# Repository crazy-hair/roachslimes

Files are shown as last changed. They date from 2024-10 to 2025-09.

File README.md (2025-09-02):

# roachslimes

This document is no longer being updated and will only be corrected on major updates! For full documentation please check out [The Docs](https://crazy-hair.github.io/roachslimes/)

A utilitarian tracker design for [SlimeVR](https://docs.slimevr.dev/), with the intention of using the cheapest parts available in the smallest form factor possible, while maintaining quality and usability.

## Ordering PCBs

**NEW!** Revision 2 motherboards have been added, removing the BMI160-QMC5883 IMU-Magnetometer combo, and replacing it with an [LSM6DSR](https://moffshop.deyta.de/products/lsm6dsr) board which has a magnetometer built in. Technically, the LSM6DSR board is pin-compatible with the BMI160 (and therefore is compatible with the old rev 1 boards), but this new design allows for much easier direct mounting (instead of using pin headers) and frees up space for a battery connector, instead of directly soldering the battery to the board. They're currently untested, still waiting for my batch to arrive, so use at your own risk!

The included gerbers in `/PCB/Production/` are exported from KiCad using the recommended settings for [JLCPCB](https://jlcpcb.com). I cannot guarantee that they will work at a different fab. JLCPCB is far and away the most cost effective for low volume PCB orders, coming out to $3.52 for 20 boards before tax if you use their economy shipping option (as of 2024). There are four files, two for each board (one single board, and one panelized). Using the panelized board files is highly recommended, as it allows for More Board Per Board<sup>TM</sup> without additional cost. The default JLCPCB order parameters are good enough for working boards out of the box, but I'd recommend changing the color to yellow [(because it's lemon scented)](https://x.com/MKVRiscy/status/1821870120697987492) and to select "no mark" so you don't have some unique identifier printed on the board somewhere.

## Ordering Parts

Links to all required components can be found in the table futher down.

## Printing Instructions

The print files, STLs, and Fusion source files are included in the `/3D Files/` directory. I highly recommend using the `.3mf` print files as a basis for your print, as there are manually painted supports and custom settings per object (there's one `.3mf` for PrusaSlicer and friends and one for OrcaSlicer and friends).

## Assembly

This board is designed to be compact, which means I had to make some unconventional choices during assembly. The D1 Mini and TP-4056 Boards are mounted to the surface of the PCB, while the BMI and QMC are mounted on headers on the opposite side. For assembly, this means you have to solder the headers on first, then use flush cutters or snips to cut the header pins sticking out of the front of the board down to be flush so you can solder on the boards on the onto the front. There's also a pogo pin header for a future modular charging dock which would allow for charging multiple trackers at once, and a slot for an LED and associated resistor which was added for debugging but can be used to identify trackers if you choose to use different colored LEDs per tracker. The cases are completely toolless and are friction/retention fit. Refer to the animation below for an assembly reference.

## Firmware

Firmware is pretty straightforward, though I did have an issue with the Butterscotch builder/installer - battery sense would always show 100 percent. Therefore, if you want all features to work, I'd recommend building it yourself - PlatformIO Tools for Visual Studio Code make it super easy. If you're compiling yourself, all you have to do is uncomment out `BATTERY_SHIELD_RESISTANCE 180` in `defines.h`, set `USE_6_AXIS false` in `debug.h`, and and change `BMI160_MAG_TYPE BMI160_MAG_TYPE_HMC` to `BMI160_MAG_TYPE BMI160_MAG_TYPE_QMC`in `defines_bmi160.h`. If that makes no sense to you, I've included compiled firmware in the releases section. 

## Price Breakdown

A fully parametric breakdown that allows for adjusting tax, quantity, and more can be found in BOM.xlsx or [here](https://docs.google.com/spreadsheets/d/1RTwIJsGUY1e1f047yFT5OwqJSmgT3SN4hO7gHYImR_g/copy) (if you want to modify it, you'll have to make a copy first).

All prices are in USD. Sales tax is calculated at 8.25%. The table is based on a full set of trackers and includes 2 extra D1s, BMIs, and QMCs to account for possible DOA parts or accidents during assembly. Note that the LED and associated 620Ω resistor, as well as the pogo pins are not necessary for core tracker operation, as specified in the comment row.

| Tracker Components | [D1 Mini v4](https://www.aliexpress.us/item/32831353752.html) | [BMI160](https://www.aliexpress.us/item/1005007143698152.html) | [TP-4056](https://www.aliexpress.us/item/1005006379403615.html) | [GY-271](https://www.aliexpress.us/item/1556804905.html) | [SK12D07VG4](https://www.aliexpress.us/item/3256806149664764.html) | [JST-PH-4P](https://www.aliexpress.us/item/33011797617.html) | [Pogo Female](https://www.aliexpress.us/item/3256804960956555.html) | [B5817WS](https://www.aliexpress.us/item/1005004633629467.html) | [0805 180k](https://www.aliexpress.us/item/1005007032369041.html) | [0806 620r](https://www.aliexpress.us/item/3256806846054289.html) | [0805 LED](https://www.aliexpress.us/item/3256805245629305.html) | [803450](https://www.aliexpress.us/item/1005003621836701.html) | [Wires](https://www.aliexpress.us/item/1005007558078161.html) | Motherboard | Daughterboard | Total |
| --- | --- | --- | --- | --- | --- | --- | --- | --- | --- | --- | --- | --- | --- | --- | --- | --- |
| Listing Price | $1.43 | $0.88 | $3.27 | $0.58 | $1.20 | $3.79 | $12.93 | $1.20 | $1.05 | $1.05 | $2.47 | $25.99 | $11.93 | $2.00 | $2.00 | |
| Shipping | $2.63 | $2.32 | $ \- | $ \- | $ \- | $ \- | $ \- | $ \- | $ \- | $ \- | $ \- | $ \- | $ \- | $1.52 | $1.52 | $7.99 |
| Subtotal | $15.50 | $12.88 | $3.27 | $6.96 | $1.20 | $3.79 | $12.93 | $1.20 | $1.05 | $1.05 | $2.47 | $25.99 | $11.93 | $3.52 | $3.52 | $107.26 |
| Tax | $1.28 | $1.06 | $0.27 | $0.57 | $0.10 | $0.31 | $1.07 | $0.10 | $0.09 | $0.09 | $0.20 | $2.14 | $0.98 | $0.29 | $0.29 | $8.85 |
| Total | $16.78 | $13.94 | $3.54 | $7.53 | $1.30 | $4.10 | $14.00 | $1.30 | $1.14 | $1.14 | $2.67 | $28.13 | $12.91 | $3.81 | $3.81 | $116.11 |
| Order Quantity | 9 | 12 | 1 | 12 | 1 | 1 | 1 | 1 | 1 | 1 | 1 | 1 | 1 | 1 | 1 | |
| Item Quantity | 1 | 1 | 20 | 1 | 20 | 100 | 20 | 100 | 100 | 100 | 600 | 10 | 12 | 20 | 40 | |
| Price Per Unit | $1.86 | $1.16 | $0.18 | $0.63 | $0.06 | $0.04 | $0.70 | $0.01 | $0.01 | $0.01 | $0.00 | $2.81 | $1.08 | $0.19 | $0.10 | |
| | | | | | | | | | | | | | | | | |
| Quantity Per Primary Tracker | 1 | 1 | 1 | 1 | 1 | 1 | 1 | 2 | 1 | 1 | 1 | 1 | 0 | 1 | 0 | |
| Quantity Per Secondary Tracker | 0 | 1 | 0 | 1 | 0 | 1 | 0 | 0 | 0 | 0 | 0 | 0 | 1 | 0 | 1 | |
| | | | | | | | | | | | | | | | | |
| Price Per Primary Tracker | $1.86 | $1.16 | $0.18 | $0.63 | $0.06 | $0.04 | $0.70 | $0.03 | $0.01 | $0.01 | $0.00 | $2.81 | $ \- | $0.19 | $ \- | $7.69 |
| Price Per Secondary Tracker | $ \- | $1.16 | $ \- | $0.63 | $ \- | $0.04 | $ \- | $ \- | $ \- | $ \- | $ \- | $ \- | $1.08 | $ \- | $0.10 | $3.00 |
| | | | | | | | | | | | | | | | | |
| Comment | | | | | | | Optional | | | Optional | Optional | | | | | |

## Gallery

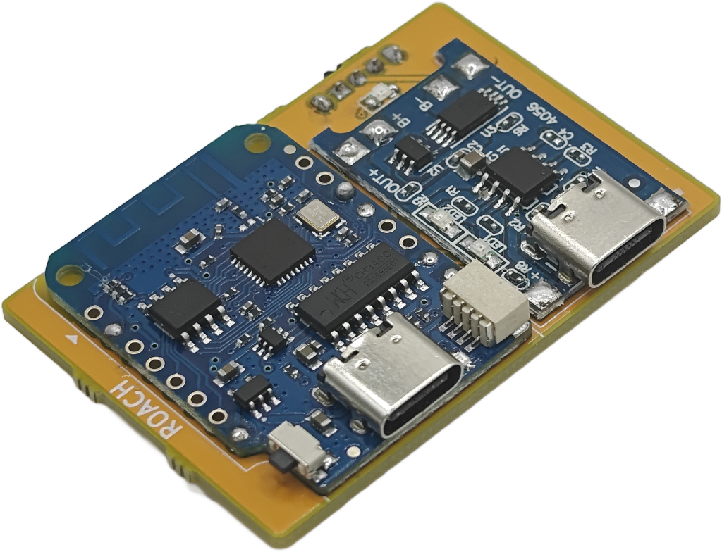
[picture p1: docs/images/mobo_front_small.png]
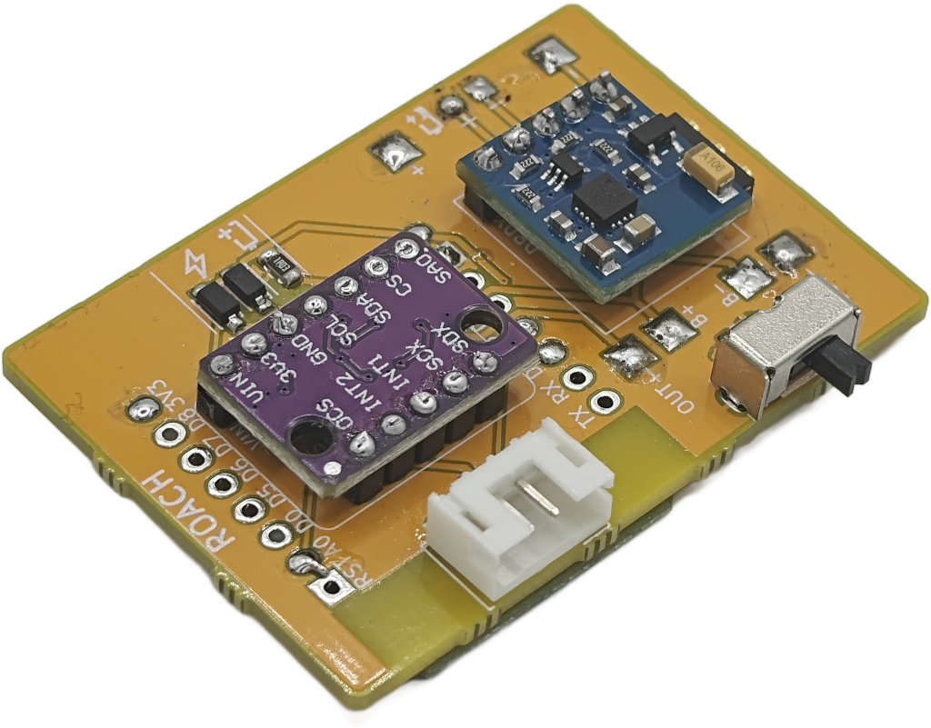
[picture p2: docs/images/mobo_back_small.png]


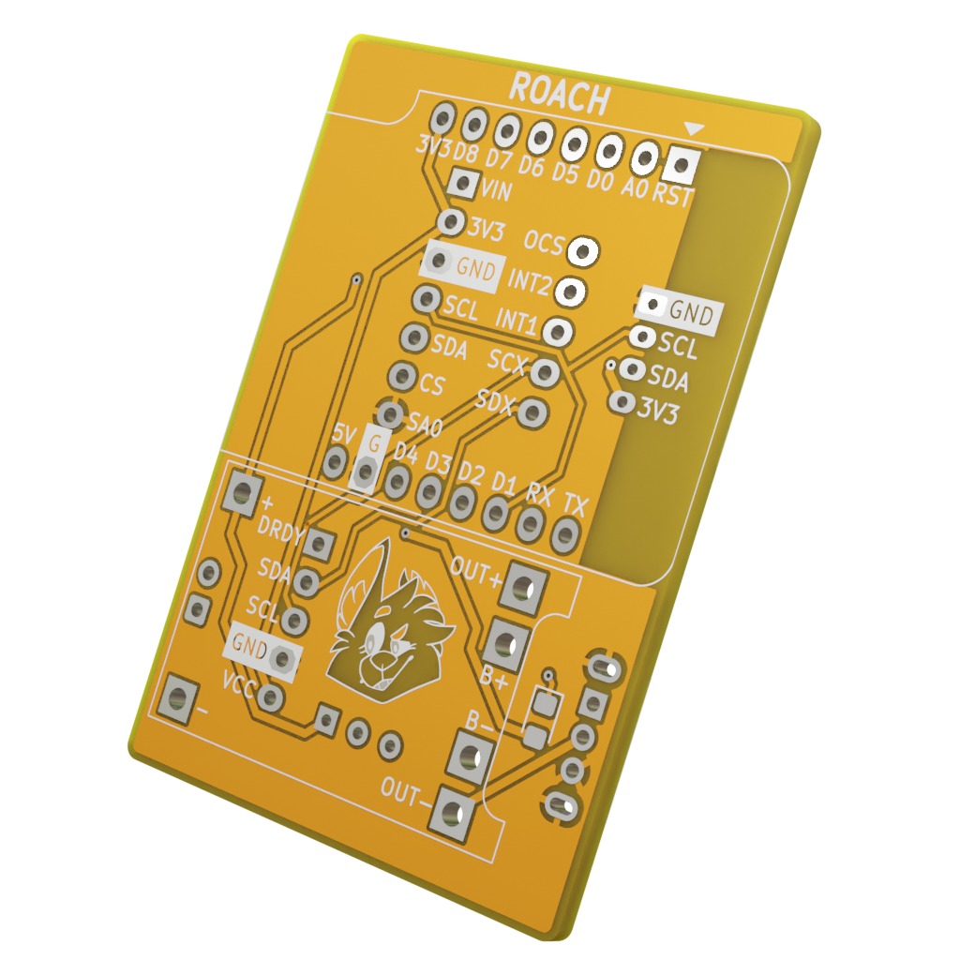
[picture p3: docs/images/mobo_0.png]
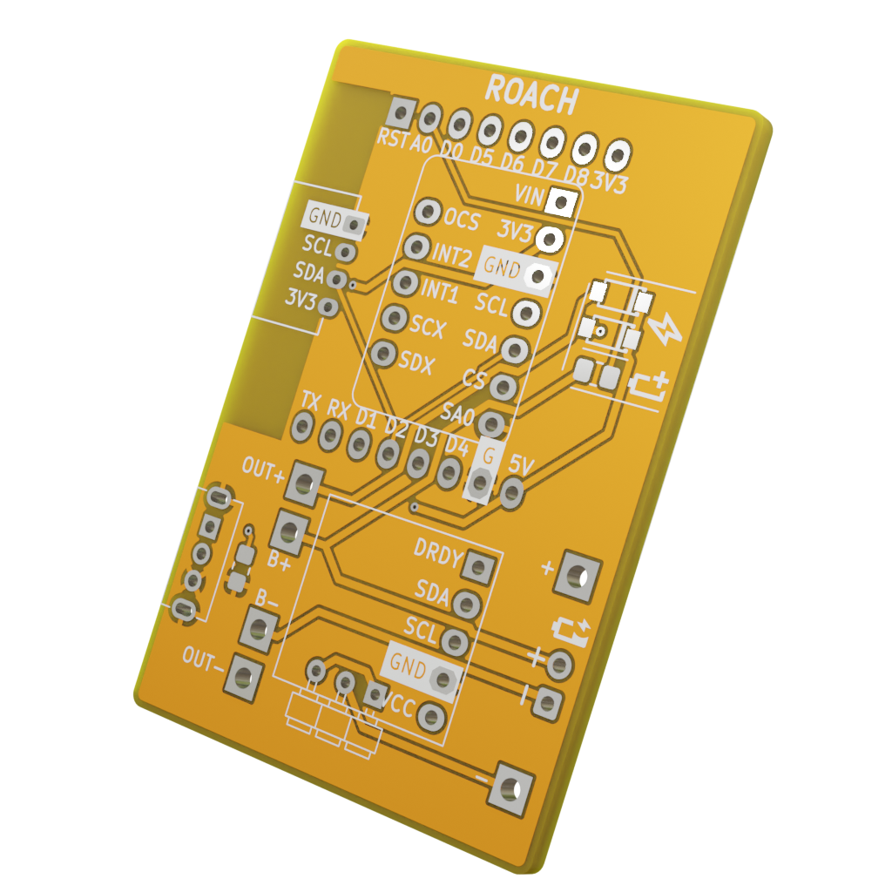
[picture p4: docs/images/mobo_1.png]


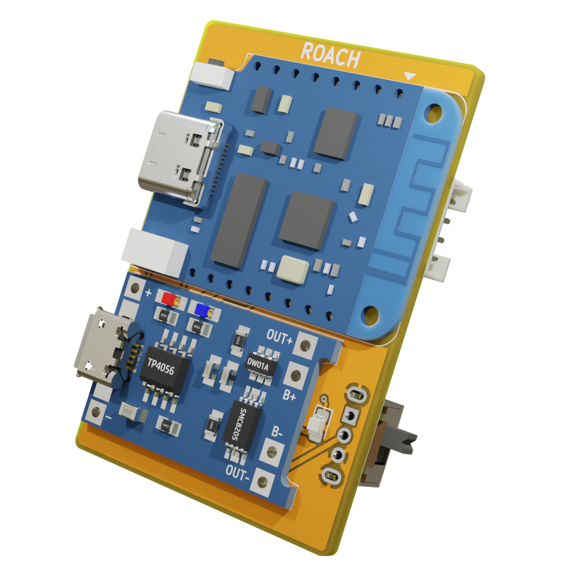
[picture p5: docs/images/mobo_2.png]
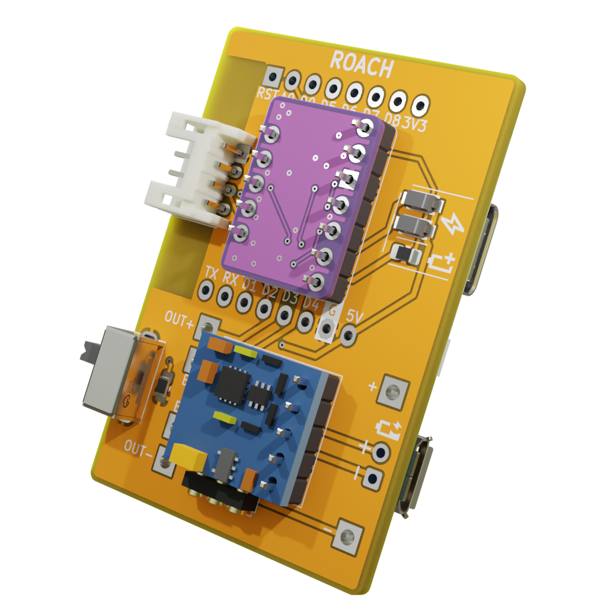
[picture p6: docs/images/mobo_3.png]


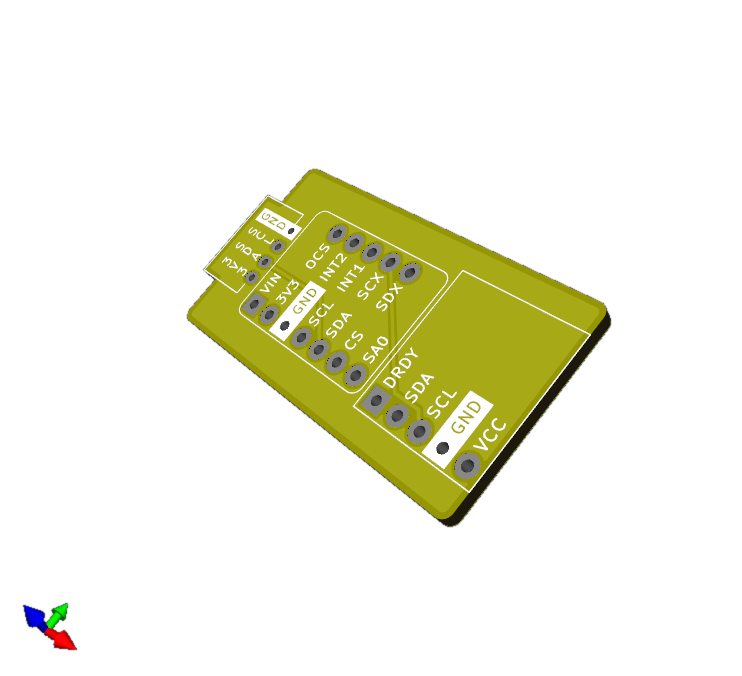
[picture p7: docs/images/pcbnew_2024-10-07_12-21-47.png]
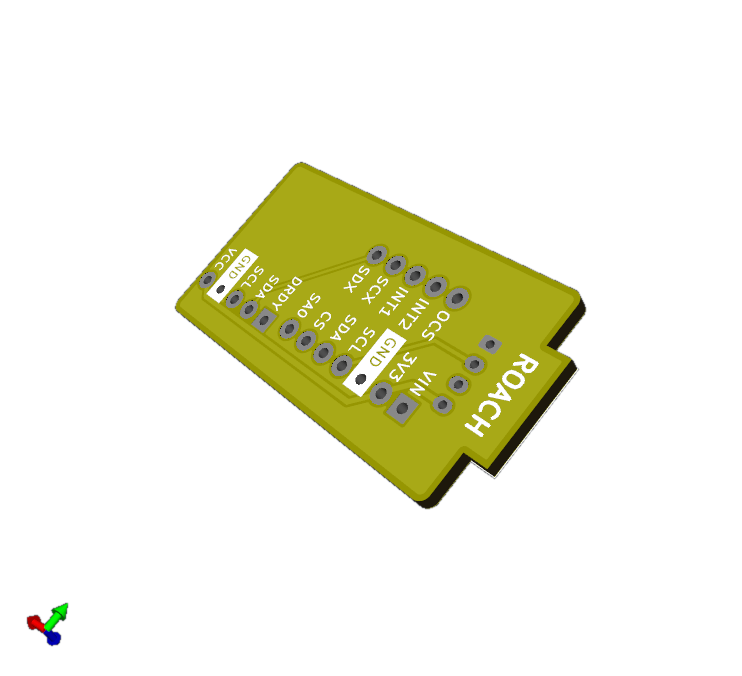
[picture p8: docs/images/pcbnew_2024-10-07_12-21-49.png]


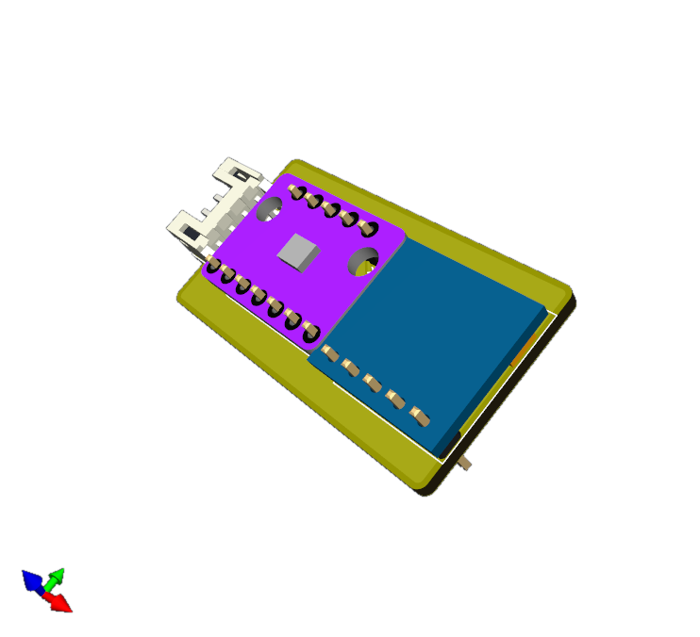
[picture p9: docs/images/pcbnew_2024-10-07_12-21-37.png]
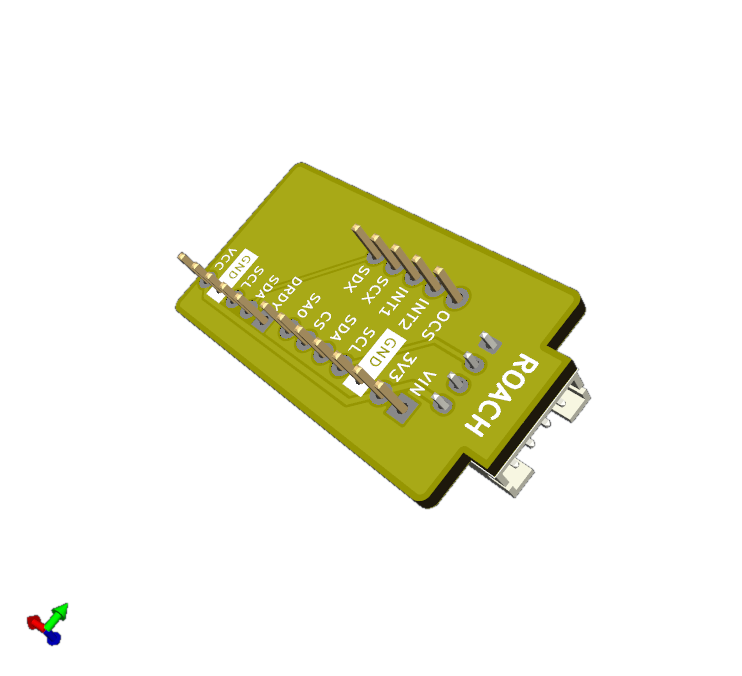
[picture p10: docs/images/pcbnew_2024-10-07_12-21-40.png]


## Credits

List of models used:

| Model | Credit |
|--|--:|
| Wemos D1 Mini v4 | [FBMinis](https://grabcad.com/library/wemos-esp8266-lolin-d1-mini-v4-1) |
| TP-4056 | [Babu George](https://grabcad.com/library/03962a-hw107-lithium-battery-charging-module-1) |
| BMI160 | [Kouno](https://store.kouno.xyz/products/bmi270-breakout-board) |
| GY-271 | [Benas Griauzde](https://grabcad.com/library/gy-271-hmc5883l-triple-3-axis-digital-compass-magnetometer-sensor-module-1) |

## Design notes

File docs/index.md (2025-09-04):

---
title: Main Page
nav_order: 0
---

This documentation is a work in progress! If you have any questions, feel free to send me a message request on discord at `crazy.hair`.

# roachslimes

A utilitarian DIY tracker design for [SlimeVR](https://docs.slimevr.dev/), with the intention of using the cheapest parts available in the smallest form factor possible, while maintaining quality, usability, and the ability to be built by hand.

Check out the sidebar for more information on building them yourself!

**NEW!** Revision 2 motherboards have been added, removing the BMI160-QMC5883 IMU-Magnetometer combo, and replacing it with an [LSM6DSR](https://moffshop.deyta.de/products/lsm6dsr) board which has a magnetometer built in. Technically, the LSM6DSR board is pin-compatible with the BMI160 (and therefore is compatible with the old rev 1 boards), but this new design allows for much easier direct mounting (instead of using pin headers) and frees up space for a battery connector, instead of directly soldering the battery to the board. They're currently untested, still waiting for my batch to arrive, so use at your own risk!

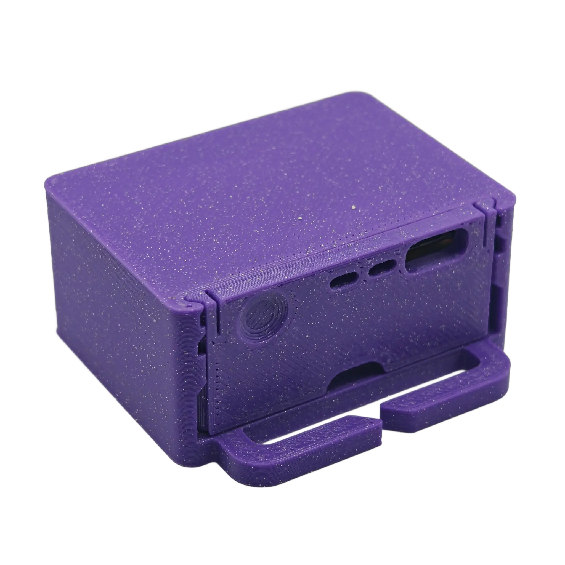
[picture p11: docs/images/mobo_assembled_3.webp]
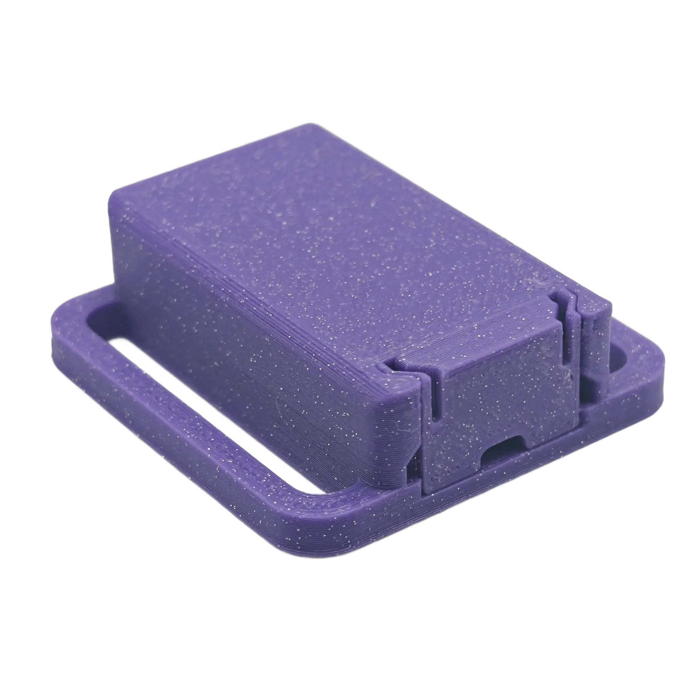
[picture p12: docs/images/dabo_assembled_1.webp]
  <br>

Feel free to take the boards for a spin, they're 3D models!

<iframe src="rendering/mobo_viewer.html" name="mobo_viewer" scrolling="no" frameborder="1" marginheight="0px" marginwidth="0px" style="width:49%; aspect-ratio:1/1; border-width: 0" allowfullscreen></iframe>
<iframe src="rendering/dabo_viewer.html" name="dabo_viewer" scrolling="no" frameborder="1" marginheight="0px" marginwidth="0px" style="width:49%; aspect-ratio:1/1; border-width: 0" allowfullscreen></iframe>

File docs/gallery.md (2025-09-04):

---
title: Gallery
nav_order: 5
---

# Gallery
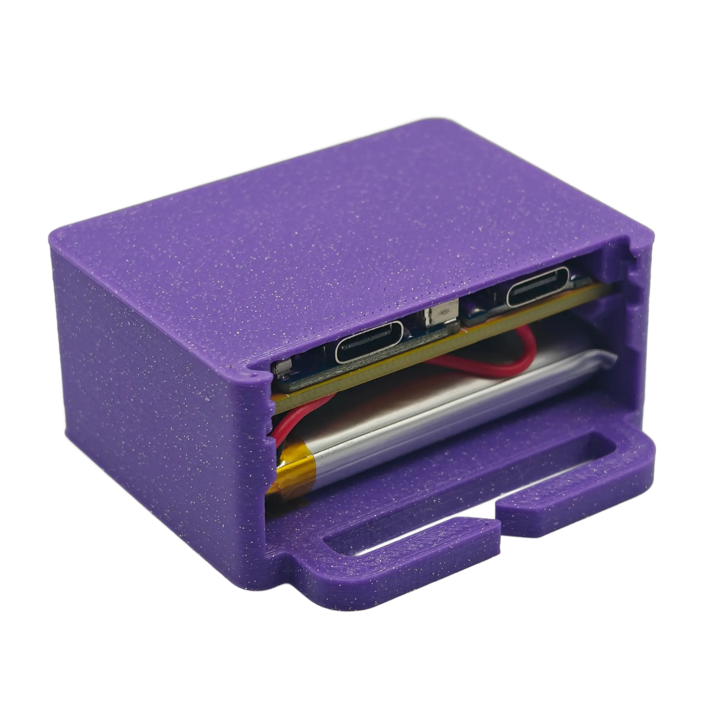
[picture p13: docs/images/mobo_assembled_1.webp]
  <br>
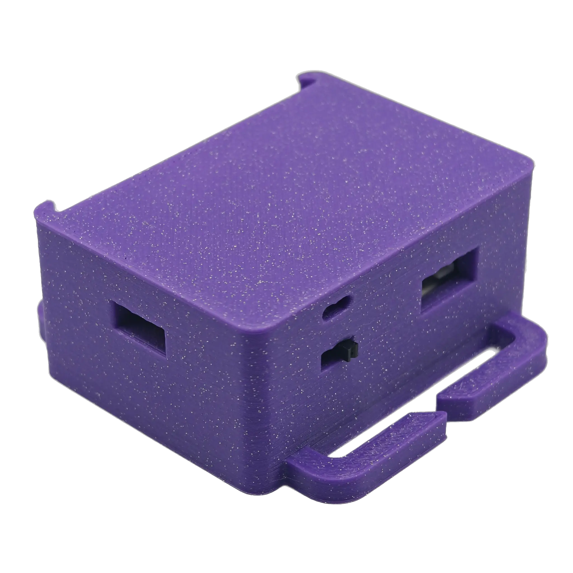
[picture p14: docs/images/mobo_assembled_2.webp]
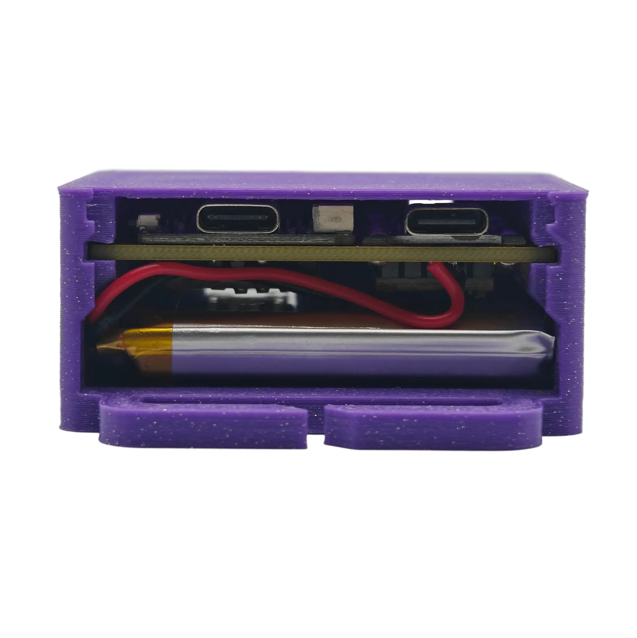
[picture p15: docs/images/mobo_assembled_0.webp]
  <br>
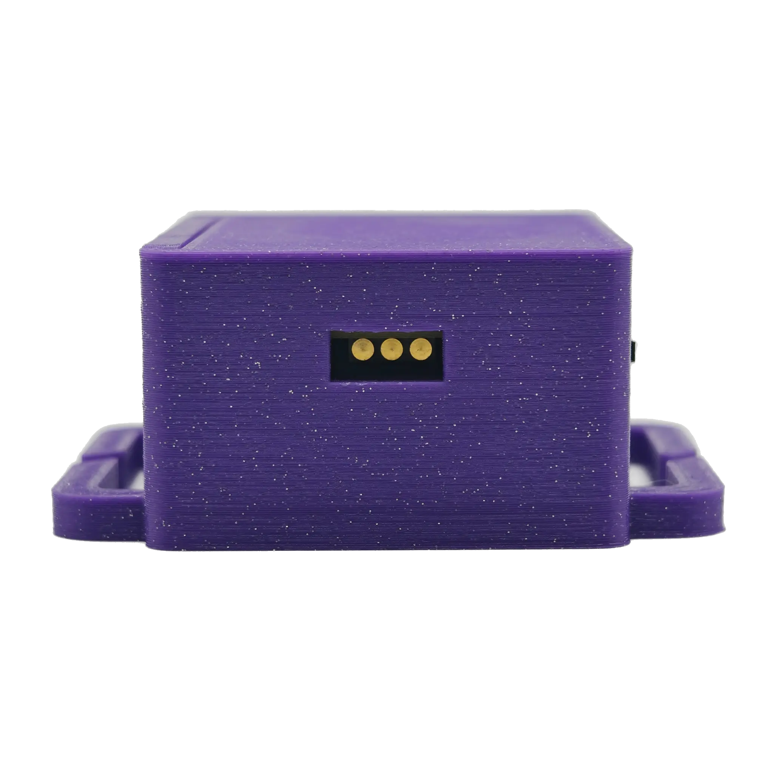
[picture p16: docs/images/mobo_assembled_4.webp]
  <br>
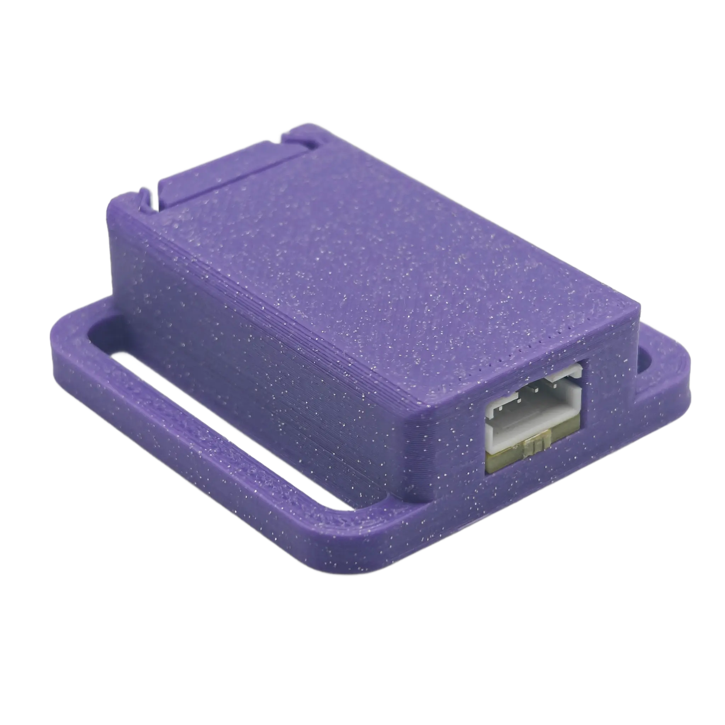
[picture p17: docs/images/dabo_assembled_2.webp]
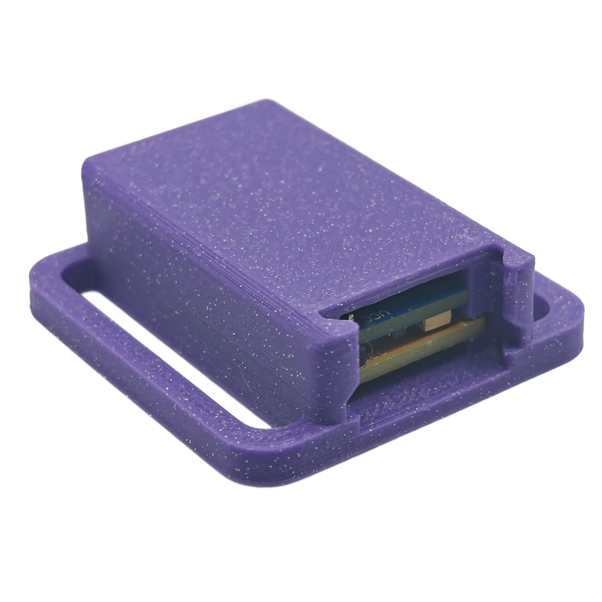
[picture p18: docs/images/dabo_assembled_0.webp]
  <br>
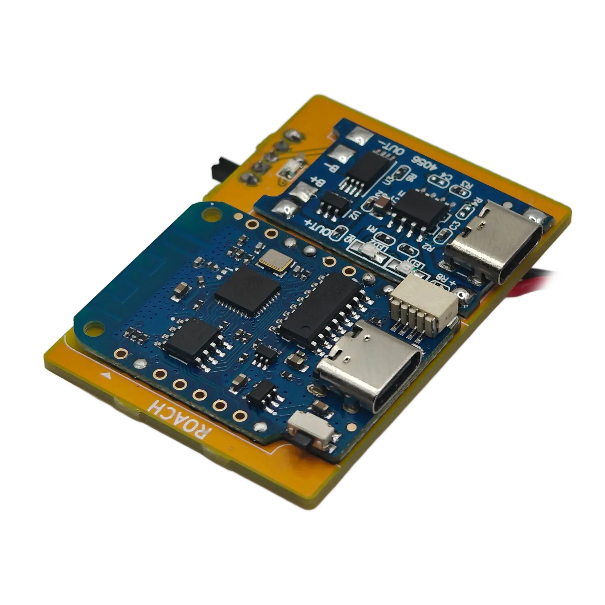
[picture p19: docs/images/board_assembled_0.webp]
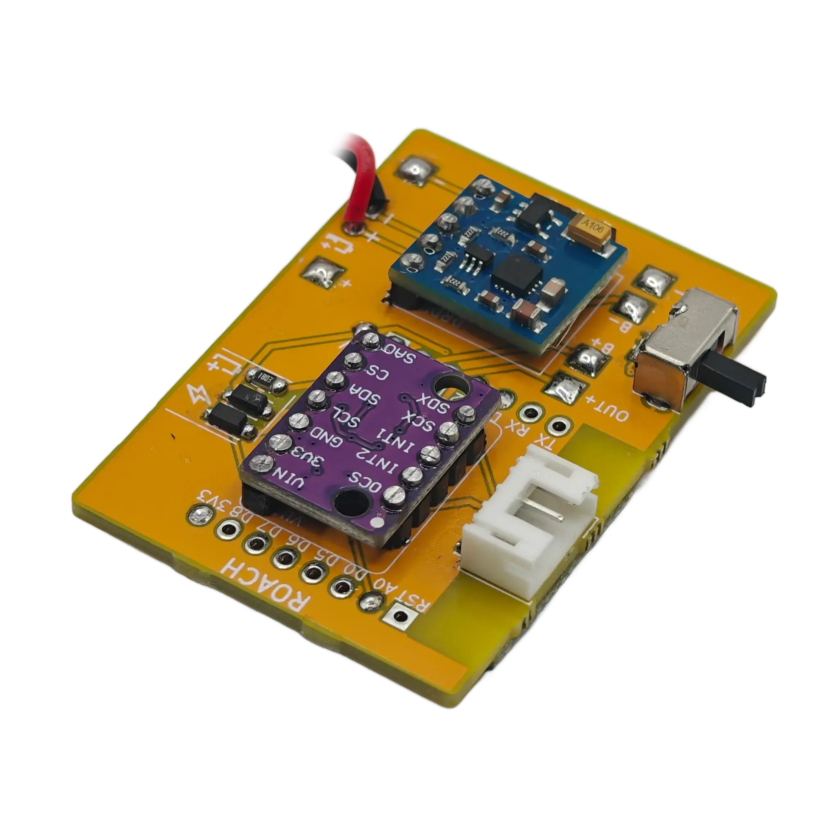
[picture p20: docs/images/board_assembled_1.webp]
  <br>
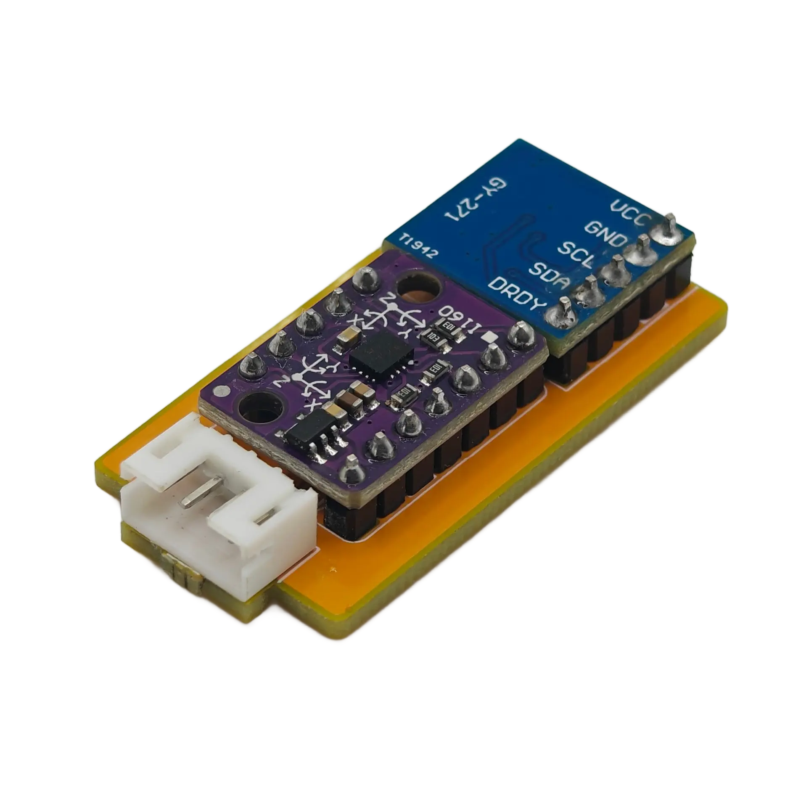
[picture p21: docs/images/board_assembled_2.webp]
 <br>
  <br>
  <br>
  <br>
  <br>

<video src="videos/floatybouncy_mobo.mp4" style="width:49%" autoplay loop muted></video> <video src="videos/floatybouncy_dabo.mp4" style="width:49%" autoplay loop muted></video> <br>
<video style="width:49%" src="videos/floatybouncy_mobo_case.mp4" autoplay loop muted></video> <video src="videos/floatybouncy_dabo_case.mp4" style="width:49%" autoplay loop muted></video> <br>

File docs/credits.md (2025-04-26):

---
title: Credits
nav_order: 6
---

# Credits

All PCB design, CAD, animation, rendering, and pretty much everything else was done by me.

As for all the stuff that I didn't make:

The SlimeVR spec and software were all designed by the [SlimeVR dev team](https://slimevr.dev/). Without them, this project wouldn't exist at all!

List of models used:

| Model | Credit |
|--|--:|
| Wemos D1 Mini v4 | [FBMinis](https://grabcad.com/library/wemos-esp8266-lolin-d1-mini-v4-1) |
| TP-4056 | [Babu George](https://grabcad.com/library/03962a-hw107-lithium-battery-charging-module-1) |
| BMI160 | [Kouno](https://store.kouno.xyz/products/bmi270-breakout-board) |
| GY-271 | [Benas Griauzde](https://grabcad.com/library/gy-271-hmc5883l-triple-3-axis-digital-compass-magnetometer-sensor-module-1) |

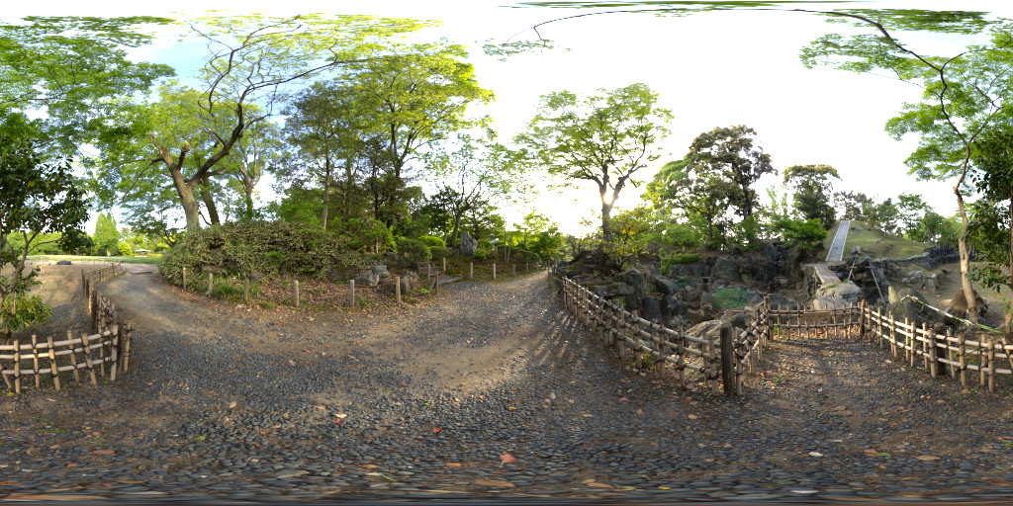
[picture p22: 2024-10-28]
docs/rendering/ninomaru_teien_1k.jpg

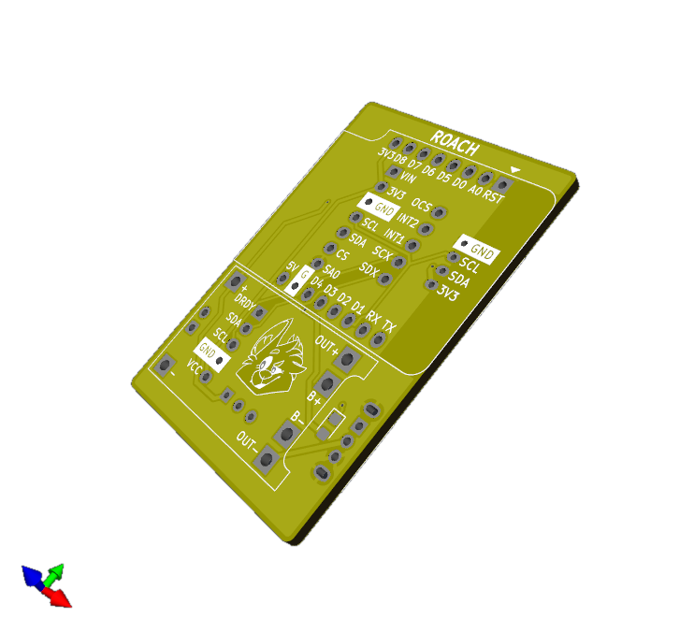
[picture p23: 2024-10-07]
docs/images/pcbnew_2024-10-07_12-25-15.png

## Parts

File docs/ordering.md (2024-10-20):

---
title: Sourcing and Ordering Parts
nav_order: 1
---

# Ordering PCBs

The included gerbers in [`/PCB/Production/`](https://github.com/crazy-hair/roachslimes/tree/main/PCB/Production) are exported from KiCad using the recommended settings for [JLCPCB](https://jlcpcb.com). I cannot guarantee that they will work at a different fab. JLCPCB is far and away the most cost effective for low volume PCB orders, coming out to $3.52 for 20 boards before tax if you use their economy shipping option (as of 2024). There are four files, two for each board (one single board, and one panelized). Using the panelized board files is highly recommended, as it allows for More Board Per Board<sup>TM</sup> without additional cost. The default JLCPCB order parameters are good enough for working boards out of the box, but I'd recommend changing the color to yellow [(because it's lemon scented)](https://x.com/MKVRiscy/status/1821870120697987492) and to select "no mark" so you don't have some unique identifier printed on the board somewhere.

# Ordering Parts

Links to all required components can be found in the headers of the table. 

A fully parametric breakdown that allows for adjusting tax, quantity, and more can be found in the Excel file [BOM.xlsx](https://github.com/crazy-hair/roachslimes/blob/main/BOM.xlsx) or [the Google Sheets page](https://docs.google.com/spreadsheets/d/1RTwIJsGUY1e1f047yFT5OwqJSmgT3SN4hO7gHYImR_g/copy) (if you want to modify it, you'll have to make a copy first).

All prices are in USD. Sales tax is calculated at 8.25%. The table is based on a full set of trackers and includes 2 extra D1s, BMIs, and QMCs to account for possible DOA parts or accidents during assembly. Note that the LED and associated 620Ω resistor, as well as the pogo pins are not necessary for core tracker operation, as specified in the comment row.

The table scrolls horizontally, it was too wide to fit.

| Tracker Components | [D1 Mini v4](https://www.aliexpress.us/item/32831353752.html) | [BMI160](https://www.aliexpress.us/item/1005007143698152.html) | [TP-4056](https://www.aliexpress.us/item/1005006379403615.html) | [GY-271](https://www.aliexpress.us/item/1556804905.html) | [SK12D07VG4](https://www.aliexpress.us/item/3256806149664764.html) | [JST-PH-4P](https://www.aliexpress.us/item/33011797617.html) | [Pogo Female](https://www.aliexpress.us/item/3256804960956555.html) | [B5817WS](https://www.aliexpress.us/item/1005004633629467.html) | [0805 180k](https://www.aliexpress.us/item/1005007032369041.html) | [0806 620r](https://www.aliexpress.us/item/3256806846054289.html) | [0805 LED](https://www.aliexpress.us/item/3256805245629305.html) | [803450](https://www.aliexpress.us/item/1005003621836701.html) | [Wires](https://www.aliexpress.us/item/1005007558078161.html) | Motherboard | Daughterboard | Total |
| --- | --- | --- | --- | --- | --- | --- | --- | --- | --- | --- | --- | --- | --- | --- | --- | --- |
| Listing Price | $1.43 | $0.88 | $3.27 | $0.58 | $1.20 | $3.79 | $12.93 | $1.20 | $1.05 | $1.05 | $2.47 | $25.99 | $11.93 | $2.00 | $2.00 | |
| Shipping | $2.63 | $2.32 | $ \- | $ \- | $ \- | $ \- | $ \- | $ \- | $ \- | $ \- | $ \- | $ \- | $ \- | $1.52 | $1.52 | $7.99 |
| Subtotal | $15.50 | $12.88 | $3.27 | $6.96 | $1.20 | $3.79 | $12.93 | $1.20 | $1.05 | $1.05 | $2.47 | $25.99 | $11.93 | $3.52 | $3.52 | $107.26 |
| Tax | $1.28 | $1.06 | $0.27 | $0.57 | $0.10 | $0.31 | $1.07 | $0.10 | $0.09 | $0.09 | $0.20 | $2.14 | $0.98 | $0.29 | $0.29 | $8.85 |
| Total | $16.78 | $13.94 | $3.54 | $7.53 | $1.30 | $4.10 | $14.00 | $1.30 | $1.14 | $1.14 | $2.67 | $28.13 | $12.91 | $3.81 | $3.81 | $116.11 |
| Order Quantity | 9 | 12 | 1 | 12 | 1 | 1 | 1 | 1 | 1 | 1 | 1 | 1 | 1 | 1 | 1 | |
| Item Quantity | 1 | 1 | 20 | 1 | 20 | 100 | 20 | 100 | 100 | 100 | 600 | 10 | 12 | 20 | 40 | |
| Price Per Unit | $1.86 | $1.16 | $0.18 | $0.63 | $0.06 | $0.04 | $0.70 | $0.01 | $0.01 | $0.01 | $0.00 | $2.81 | $1.08 | $0.19 | $0.10 | |
| | | | | | | | | | | | | | | | | |
| Quantity Per Primary Tracker | 1 | 1 | 1 | 1 | 1 | 1 | 1 | 2 | 1 | 1 | 1 | 1 | 0 | 1 | 0 | |
| Quantity Per Secondary Tracker | 0 | 1 | 0 | 1 | 0 | 1 | 0 | 0 | 0 | 0 | 0 | 0 | 1 | 0 | 1 | |
| | | | | | | | | | | | | | | | | |
| Price Per Primary Tracker | $1.86 | $1.16 | $0.18 | $0.63 | $0.06 | $0.04 | $0.70 | $0.03 | $0.01 | $0.01 | $0.00 | $2.81 | $ \- | $0.19 | $ \- | $7.69 |
| Price Per Secondary Tracker | $ \- | $1.16 | $ \- | $0.63 | $ \- | $0.04 | $ \- | $ \- | $ \- | $ \- | $ \- | $ \- | $1.08 | $ \- | $0.10 | $3.00 |
| | | | | | | | | | | | | | | | | |
| Comment | | | | | | | Optional | | | Optional | Optional | | | | | |

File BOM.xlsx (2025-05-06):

Tracker Components | D1 Mini (https://www.aliexpress.us/item/32831353752.html) | BMI160 (https://www.aliexpress.us/item/1005007143698152.html) | TP4056 (https://www.aliexpress.us/item/1005006379403615.html) | GY-271 (https://www.aliexpress.us/item/1556804905.html) | SK12D07VG4 (https://www.aliexpress.us/item/3256806149664764.html) | JST-PH-4P (https://www.aliexpress.us/item/33011797617.html) | Pogo Female (https://www.aliexpress.us/item/3256804960956555.html) | B5817WS (https://www.aliexpress.us/item/1005004633629467.html) | 0805 180k (https://www.aliexpress.us/item/1005007032369041.html) | 0806 620r (https://www.aliexpress.us/item/3256806846054289.html) | 0805 LED (https://www.aliexpress.us/item/3256805245629305.html) | 803450 (https://www.aliexpress.us/item/1005003621836701.html) | Wires (https://www.aliexpress.us/item/1005007558078161.html) | Motherboard | Daughterboard | Total
Listing Price | $1.43 | $0.88 | $3.27 | $0.58 | $1.20 | $3.79 | $12.93 | $1.20 | $1.05 | $1.05 | $2.47 | $25.99 | $11.93 | $2.00 | $2.00
Shipping | $2.63 | $2.32 | $0.00 | $0.00 | $0.00 | $0.00 | $0.00 | $0.00 | $0.00 | $0.00 | $0.00 | $0.00 | $0.00 | $1.52 | $1.52 | $7.99
Subtotal | $15.50 | $12.88 | $3.27 | $6.96 | $1.20 | $3.79 | $12.93 | $1.20 | $1.05 | $1.05 | $2.47 | $25.99 | $11.93 | $3.52 | $3.52 | $107.26 |  | Tax Rate
Tax | $1.28 | $1.06 | $0.27 | $0.57 | $0.10 | $0.31 | $1.07 | $0.10 | $0.09 | $0.09 | $0.20 | $2.14 | $0.98 | $0.29 | $0.29 | $8.85 |  | 8.25%
Total | $16.78 | $13.94 | $3.54 | $7.53 | $1.30 | $4.10 | $14.00 | $1.30 | $1.14 | $1.14 | $2.67 | $28.13 | $12.91 | $3.81 | $3.81 | $116.11
Order Quantity | 9 | 12 | 1 | 12 | 1 | 1 | 1 | 1 | 1 | 1 | 1 | 1 | 1 | 1 | 1 |  |  | Materials Cost | Lower Body Set | Core Set | Enhanced Core Set | Full Body Set | Deluxe Tracker Set
Item Quantity | 1 | 1 | 20 | 1 | 20 | 100 | 20 | 100 | 100 | 100 | 600 | 10 | 12 | 20 | 40 |  |  | Primary Tracker Quantity | 5 | 5 | 5 | 7 | 10
Price Per Unit | $1.86 | $1.16 | $0.18 | $0.63 | $0.06 | $0.04 | $0.70 | $0.01 | $0.01 | $0.01 | $0.004456291667 | $2.81 | $1.08 | $0.19 | $0.10 |  |  | Secondary Tracker Quantity | 0 | 1 | 3 | 3 | 6 | Assembly Time Per Primary Tracker | 33
 |  |  |  |  |  |  |  |  |  |  |  |  |  |  |  |  |  |  |  |  |  |  |  | Assembly Time Per Secondary Tracker | 5
Quantity Per Primary Tracker | 1 | 1 | 1 | 1 | 1 | 1 | 1 | 2 | 1 | 1 | 1 | 1 | 0 | 1 | 0 |  |  | 500mm Strap Quantity | 6 | 8 | 8 | 10 | 10 | Assembly Time Per Charging Dock | 30
Quantity Per Secondary Tracker | 0 | 1 | 0 | 1 | 0 | 1 | 0 | 0 | 0 | 0 | 0 | 0 | 1 | 0 | 1 |  |  | 300mm Strap Quantity | 0 | 0 | 2 | 2 | 2
 |  |  |  |  |  |  |  |  |  |  |  |  |  |  |  |  |  |  |  |  |  |  |  | Hourly Wage | $22.00
Price Per Primary Tracker | $1.86 | $1.16 | $0.18 | $0.63 | $0.06 | $0.04 | $0.70 | $0.03 | $0.01 | $0.01 | $0.004456291667 | $2.81 | $0.00 | $0.19 | $0.00 | $7.69 |  | Price of Primary Trackers | $38.47 | $38.47 | $38.47 | $53.86 | $76.94
Price Per Secondary Tracker | $0.00 | $1.16 | $0.00 | $0.63 | $0.00 | $0.04 | $0.00 | $0.00 | $0.00 | $0.00 | $0.00 | $0.00 | $1.08 | $0.00 | $0.10 | $3.00 |  | Price of Secondary Trackers | $0.00 | $3.00 | $9.01 | $9.01 | $18.01
Comment |  |  |  |  |  |  | Optional |  |  | Optional | Optional |  |  |  |  |  |  | Price of 500mm Straps | $4.78 | $6.37 | $6.37 | $7.97 | $7.97
 |  |  |  |  |  |  |  |  |  |  |  |  |  |  |  |  |  | Price of 300mm Straps | $0.00 | $0.00 | $1.32 | $1.32 | $1.32
Ancillary Components | 38x300mm Strap (https://www.aliexpress.us/item/3256801722425879.html) | 38x500mm Strap (https://www.aliexpress.us/item/3256801722425879.html) | Chest Harness (https://www.aliexpress.us/item/2251832640172299.html)
Listing Price | $3.06 | $3.68 | $8.05 |  |  |  |  |  |  |  |  |  |  |  |  |  |  | Total Price of Set | $43.25 | $47.85 | $55.18 | $72.16 | $104.24
Shipping | $0.00 | $0.00 | $0.00
Subtotal | $6.12 | $7.36 | $8.05 |  |  |  |  |  |  |  |  |  |  |  |  |  |  | Assembly Cost | Lower Body Set | Core Set | Enhanced Core Set | Full Body Set | Deluxe Tracker Set
Tax | $0.50 | $0.61 | $0.66 |  |  |  |  |  |  |  |  |  |  |  |  |  |  | Total Price of Primary Assembly | $60.50 | $60.50 | $60.50 | $84.70 | $121.00
Total | $6.62 | $7.97 | $8.71 |  |  |  |  |  |  |  |  |  |  |  |  |  |  | Total Price of Secondary Assembly | $0.00 | $1.83 | $5.50 | $5.50 | $11.00
Order Quantity | 2 | 2 | 1 |  |  |  |  |  |  |  |  |  |  |  |  |  |  | Total Price of Assembly | $60.50 | $62.33 | $66.00 | $90.20 | $132.00
Item Quantity | 5 | 5 | 1
Price Per Unit | $0.66 | $0.80 | $8.71 |  |  |  |  |  |  |  |  |  |  |  |  |  |  | Total Price of Assembled Set | $103.75 | $110.18 | $121.18 | $162.36 | $236.24
Comment |  |  | Optional |  |  |  |  |  |  |  |  |  |  |  |  |  |  | Optional Addons | Lower Body Set | Core Set | Enhanced Core Set | Full Body Set | Deluxe Tracker Set
 |  |  |  |  |  |  |  |  |  |  |  |  |  |  |  |  | FALSE | Chest Harness | $0.00 | $0.00 | $0.00 | $0.00 | $0.00
Charging Dock Components | Pogo Male (https://www.aliexpress.us/item/2255800604645252.html) | USB-C Female SMD | PCB | Total |  |  |  |  |  |  |  |  |  |  |  |  | FALSE | Charging Dock | $0.00 | $0.00 | $0.00 | $0.00 | $0.00
Listing Price | $2.83 | $1.43 | $2.00 | $6.26 |  |  |  |  |  |  |  |  |  |  |  |  | FALSE | Identity LEDs | $0.00 | $0.00 | $0.00 | $0.00 | $0.00
Shipping | $0.00 | $0.00 | $1.52 | $1.52 |  |  |  |  |  |  |  |  |  |  |  |  | TRUE | 3D Printed Motherboard Cases | $8.45 | $8.45 | $8.45 | $11.83 | $16.90
Subtotal | $11.32 | $1.43 | $3.52 | $16.27 |  |  |  |  |  |  |  |  |  |  |  |  | TRUE | 3D Printed Daughterboard Cases | $0.00 | $0.83 | $2.49 | $2.49 | $4.98
Tax | $0.93 | $0.12 | $0.29 | $1.34
Total | $12.25 | $1.55 | $3.81 | $17.61 |  |  |  |  |  |  |  |  |  |  |  |  |  | Total Price of Addons | $8.45 | $9.28 | $10.94 | $14.32 | $21.88
Order Quantity | 4 | 1 | 1
Item Quantity | 5 | 10 | 5 |  |  |  |  |  |  |  |  |  |  |  |  |  |  | Total Price | $112.20 | $119.46 | $132.12 | $176.68 | $258.12
Price Per Unit | $0.61 | $0.15 | $0.76
Quantity Per Dock | 8 | 1 | 2
 |  |  |  |  |  | Assembled Price
Price Per Dock | $4.90 | $0.15 | $1.52 | $6.58 |  | $18.68
Comment

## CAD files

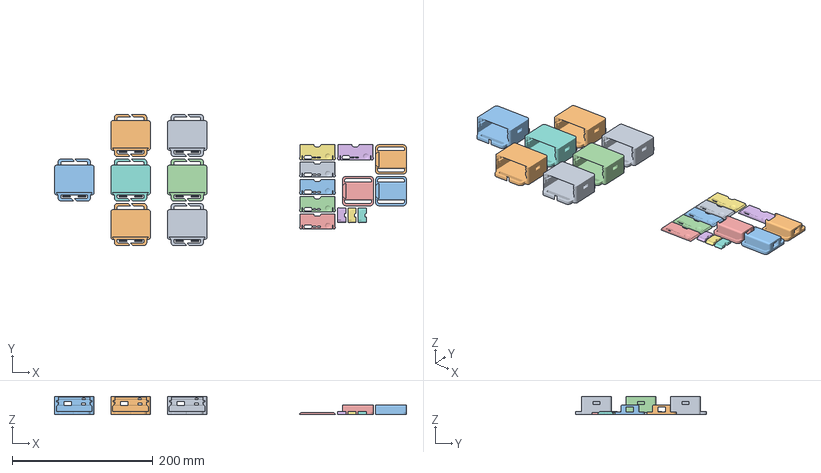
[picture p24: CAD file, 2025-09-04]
3D Files/cases_anycubic_s1.3mf
500.9 x 187.1 x 25.8 mm
Assembly x 7
roachslime_dabo_body.stl x 3
roachslime_mobo_door.stl x 6
roachslime_dabo_door.stl x 3

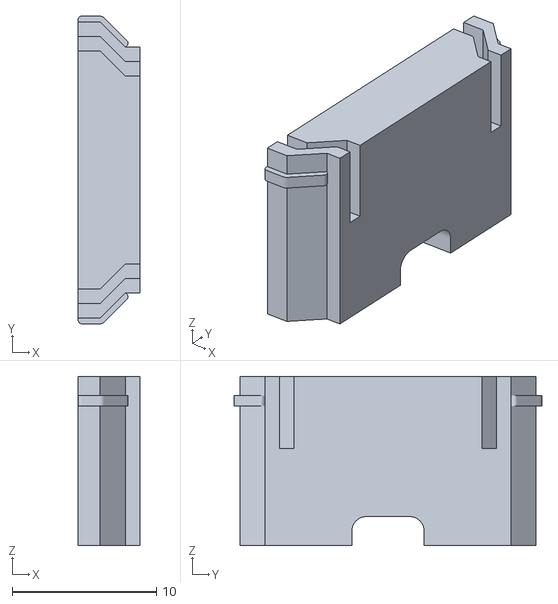
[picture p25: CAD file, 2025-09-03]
3D Files/STLs/Daughterboard/roachslime_dabo_door.stl
4.26 x 21.3 x 11.7

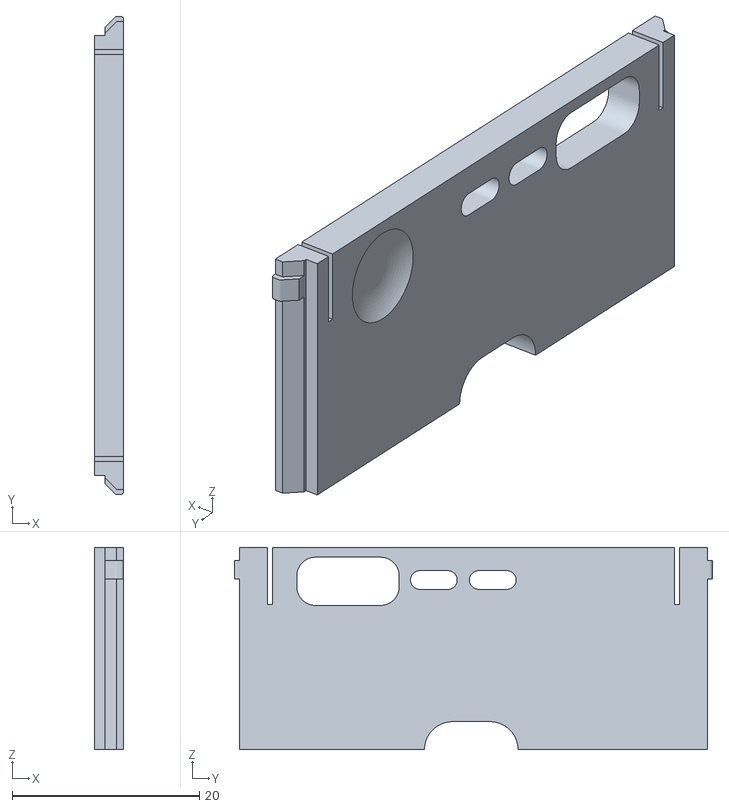
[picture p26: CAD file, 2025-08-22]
3D Files/STLs/Motherboard/v2/roachslime_mobo_door.stl
3.15 x 51.1 x 21.7

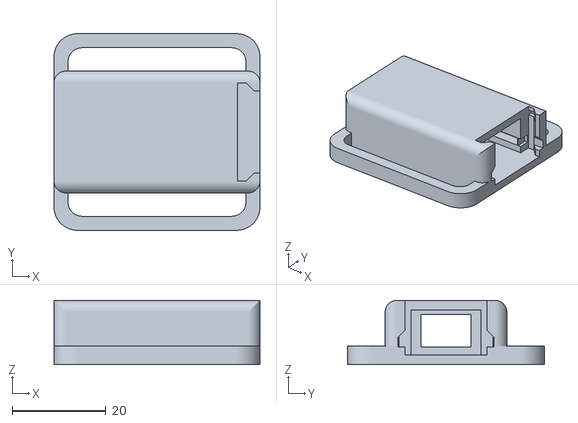
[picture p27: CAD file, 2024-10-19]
3D Files/STLs/Daughterboard/roachslime_dabo_body.stl
44.0 x 42.0 x 13.7

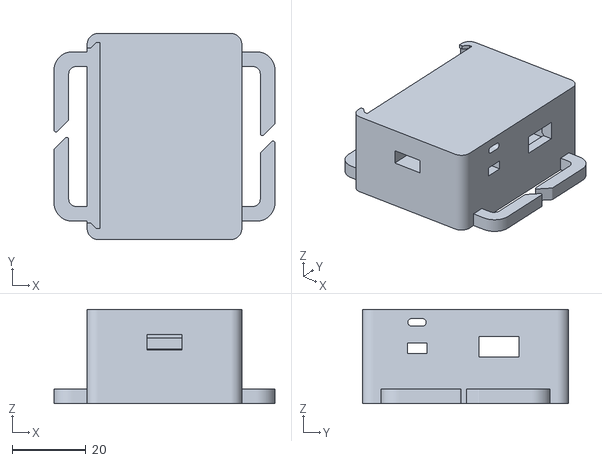
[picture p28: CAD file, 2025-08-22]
3D Files/STLs/Motherboard/v2/roachslime_mobo_body.stl
60.0 x 56.0 x 25.6

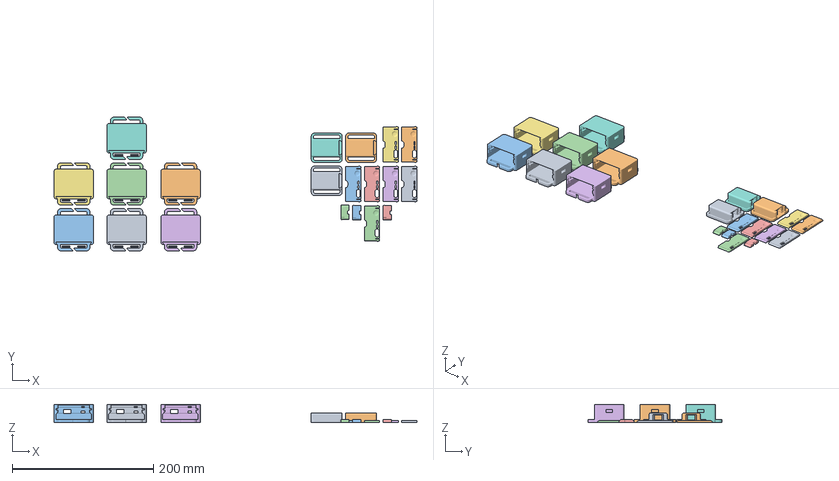
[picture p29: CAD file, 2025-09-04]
3D Files/cases.3mf
514.8 x 189.7 x 25.6 mm
roachslime_mobo_door.stl
roachslime_dabo_body.stl
roachslime_dabo_door.stl
Merged

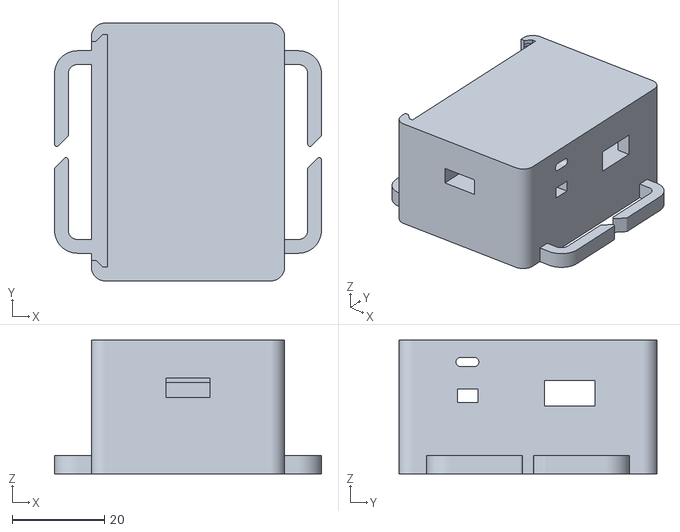
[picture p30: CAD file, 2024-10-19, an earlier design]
3D Files/STLs/Motherboard/v1/roachslime_mobo_body_slits.stl
58.0 x 56.0 x 29.0

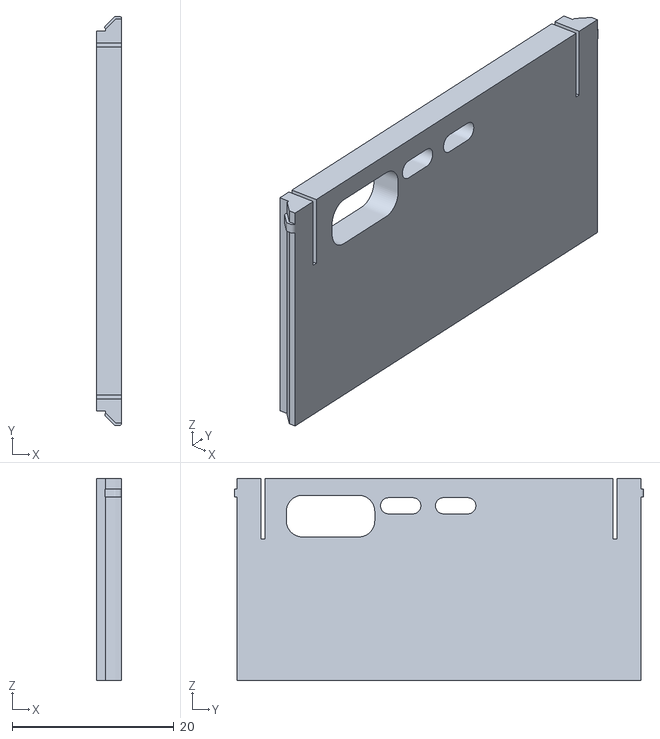
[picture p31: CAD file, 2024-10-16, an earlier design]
3D Files/STLs/Motherboard/v1/roachslime_mobo_door.stl
3.15 x 50.6 x 25.0

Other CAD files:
3D Files/cases_elegoo_centauri_carbon.3mf
3D Files/cases_orcaslicer.3mf
3D Files/STLs/Motherboard/v1/roachslime_mobo_body.stl
3D Files/Source/Daughterboard/roachslime_daughterboard_case.f3d

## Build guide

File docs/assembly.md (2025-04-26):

---
title: Assembly
nav_order: 3
---

# Assembly

IMPORTANT NOTE: If you use the v2 compact cases, you **MUST** use flush cutters to cut the excess pin length coming out of the BMI and QMC (see picture below for an example), or you risk **puncturing the battery** which could burn you, your slimes, and your house down. Please use common sense and safe practices around lithium batteries. The v1 cases have a thin layer of plastic to prevent contact, but are a few mm taller. 

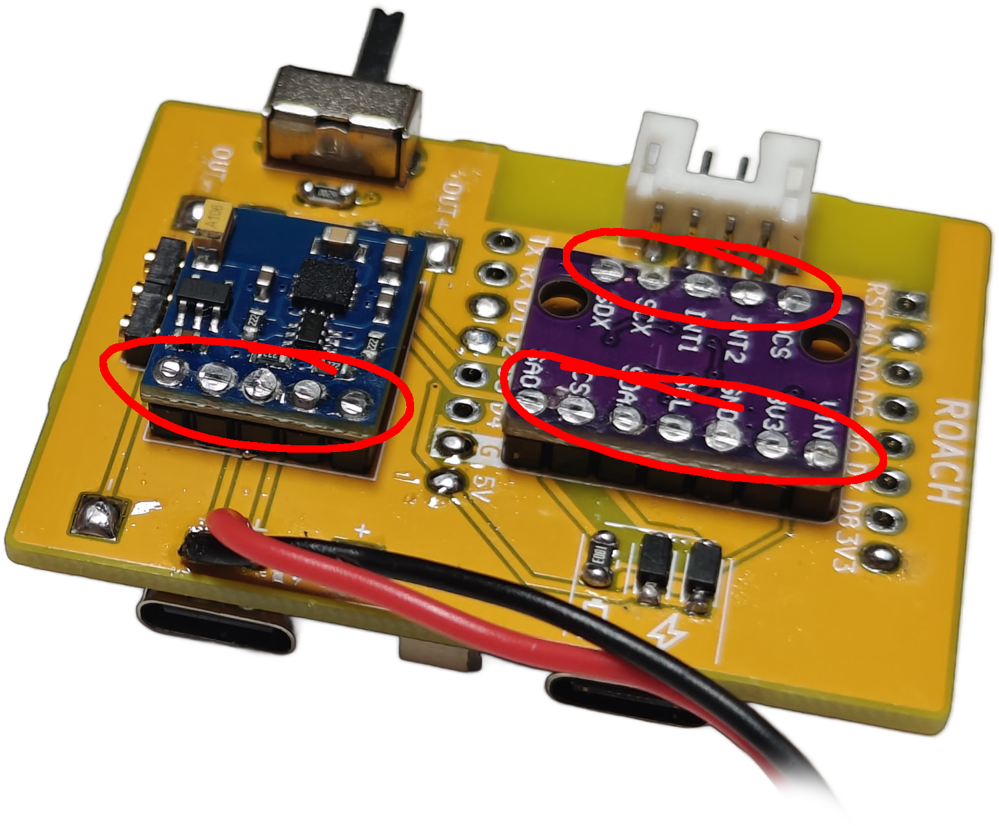
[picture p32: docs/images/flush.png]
flush_cut


This board is designed to be compact, which means I had to make some unconventional choices during assembly. The D1 Mini and TP-4056 Boards are mounted to the surface of the PCB, while the BMI and QMC are mounted on headers on the opposite side. For assembly, this means you have to solder the headers on first, then use flush cutters or snips to cut the header pins sticking out of the front of the board down to be flush so you can solder on the boards onto the front. There's also a pogo pin header for a future modular charging dock which would allow for charging multiple trackers at once, and a slot for an LED and associated resistor which was added for debugging but can be used to identify trackers if you choose to use different colored LEDs per tracker. The cases are completely toolless and are friction/retention fit. Refer to the animation below for an assembly reference.

<video style="max-width: 730px; width:100%" src="videos/speen_mobo.mp4" autoplay loop muted></video>

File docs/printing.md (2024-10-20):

---
title: 3D Printing Instructions
nav_order: 2
---

# 3D Printing Instructions

The print files, STLs, and Fusion source files are included in the [`/3D Files/`](https://github.com/crazy-hair/roachslimes/tree/main/3D%20Files) directory. I highly recommend using the `.3mf` print files as a basis for your print, as there are manually painted supports and custom settings per object (there's one `.3mf` for PrusaSlicer and friends and one for OrcaSlicer and friends).

TODO: add detailed breakdown of printing settings.

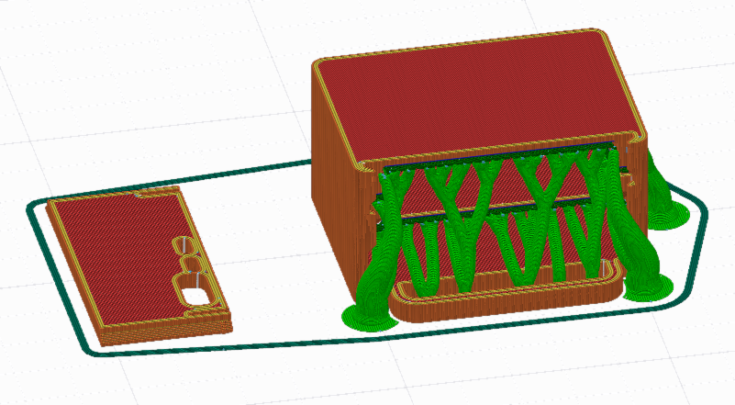
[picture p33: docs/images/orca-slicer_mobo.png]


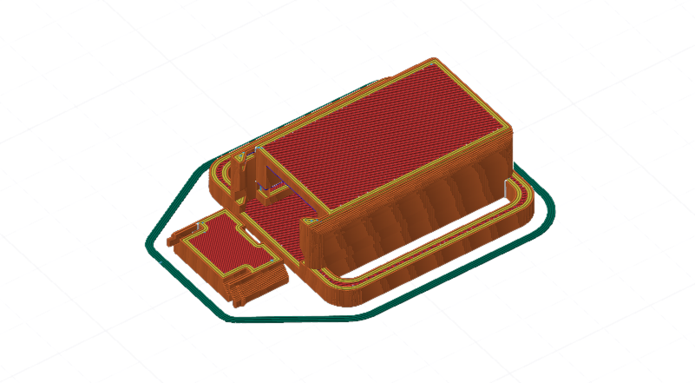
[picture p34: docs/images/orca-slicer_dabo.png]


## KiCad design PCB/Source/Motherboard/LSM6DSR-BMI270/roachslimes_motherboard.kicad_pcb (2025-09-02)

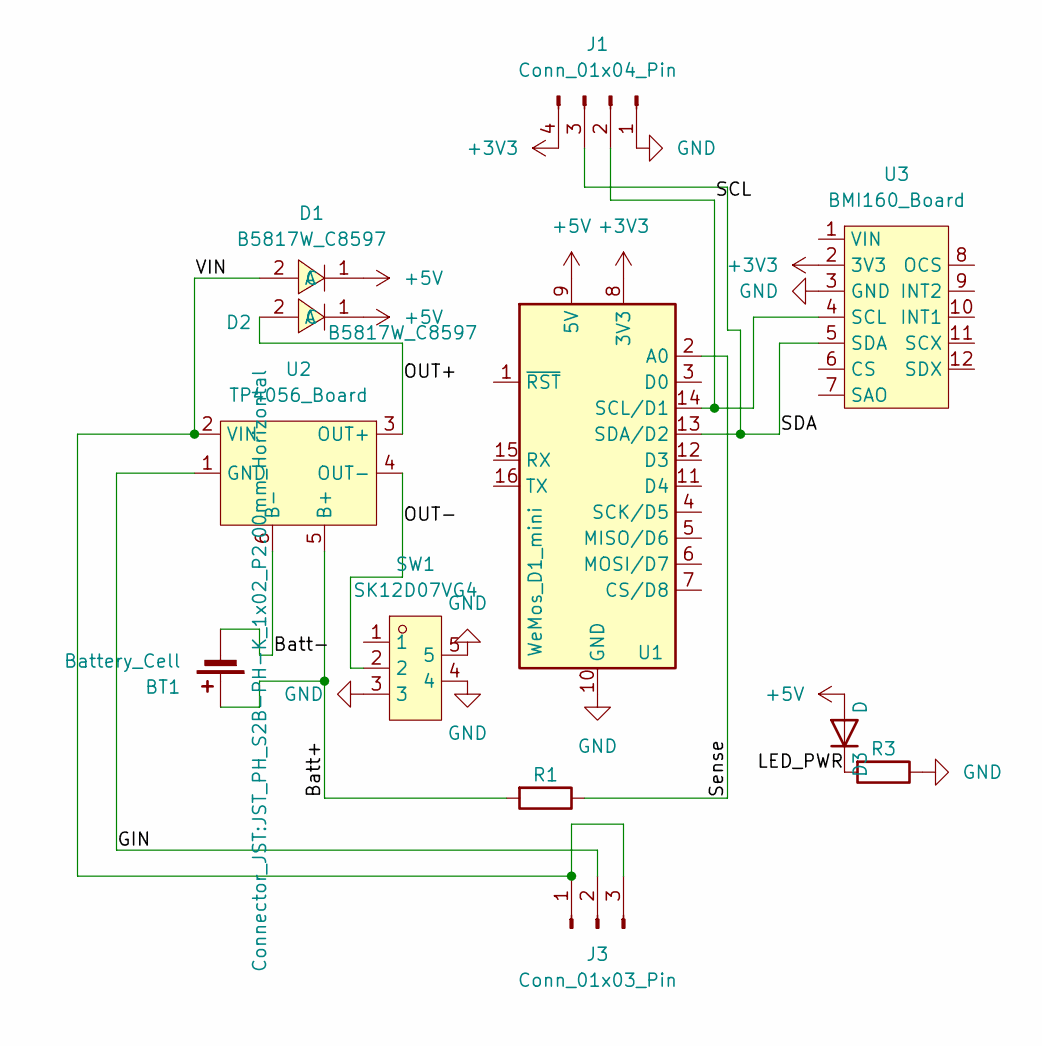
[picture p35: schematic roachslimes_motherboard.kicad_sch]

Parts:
BT1: Battery_Cell; JST_PH_S2B-PH-K_1x02_P2.00mm_Horizontal
D1, D2: B5817W_C8597; SOD-123_L2.8-W1.8-LS3.7-RD_custom; LCSC Part C8597
D3: D; LED_0805_2012Metric_Pad1.15x1.40mm_HandSolder
J1: Conn_01x04_Pin; JST_PH_S4B-PH-K_1x04_P2.00mm_Horizontal_labelled_1
J3: Conn_01x03_Pin; pogo_3_pin_right_angle
R1, R3: R; R_0805_2012Metric_Pad1.20x1.40mm_HandSolder
SW1: SK12D07VG4; SW-TH_SK12D07VG4_custom; LCSC Part C2887263
U1: WeMos_D1_mini; WEMOS_D1_mini_light_labeled_both_sides_1
U2: TP4056_Board; TP4056_both_sides_1
U3: BMI160_Board; LSM6DSR _Board

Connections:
+3V3: J1.4, U1.8 (3V3), U3.2 (3V3)
+5V: D1.1 (C), D2.1 (C), D3.2 (A), U1.9 (5V)
/Batt+: BT1.1 (+), R1.2, U2.5 (B+)
/Batt-: BT1.2 (-), U2.6 (B-)
/GIN: J3.2, U2.1 (GND)
/LED_PWR: D3.1 (K), R3.2
/OUT+: D2.2 (A), U2.3 (OUT+)
/OUT-: SW1.2, U2.4 (OUT-)
/SCL: J1.2, U1.14 (SCL/D1), U3.4 (SCL)
/SDA: J1.3, U1.13 (SDA/D2), U3.5 (SDA)
/Sense: R1.1, U1.2 (A0)
/VIN: D1.2 (A), J3.1, J3.3, U2.2 (VIN)
GND: J1.1, R3.1, SW1.3, SW1.4, SW1.5, U1.10 (GND), U3.3 (GND)

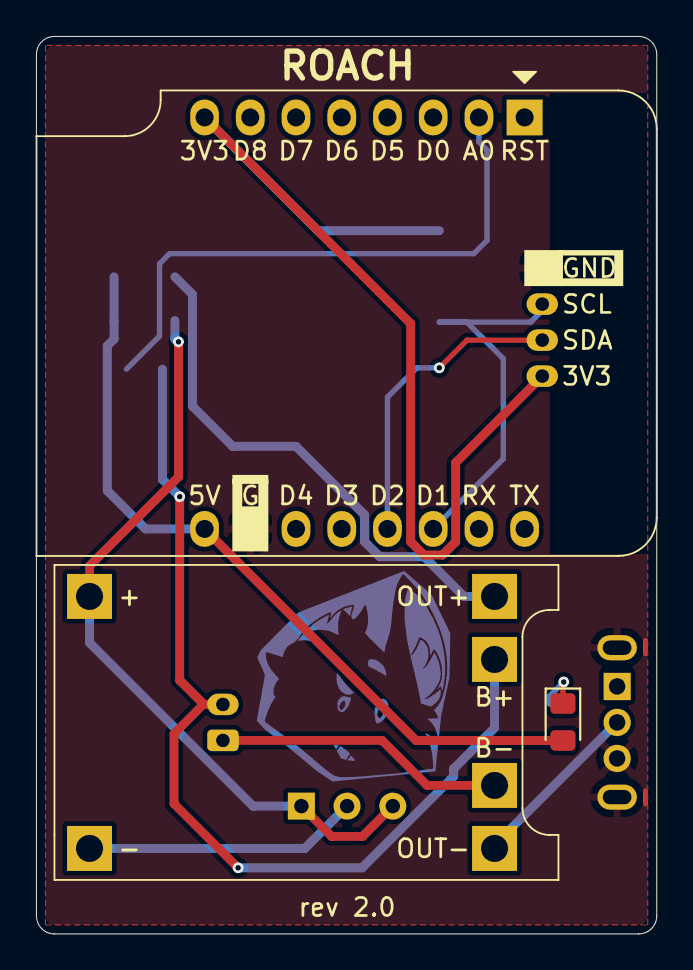
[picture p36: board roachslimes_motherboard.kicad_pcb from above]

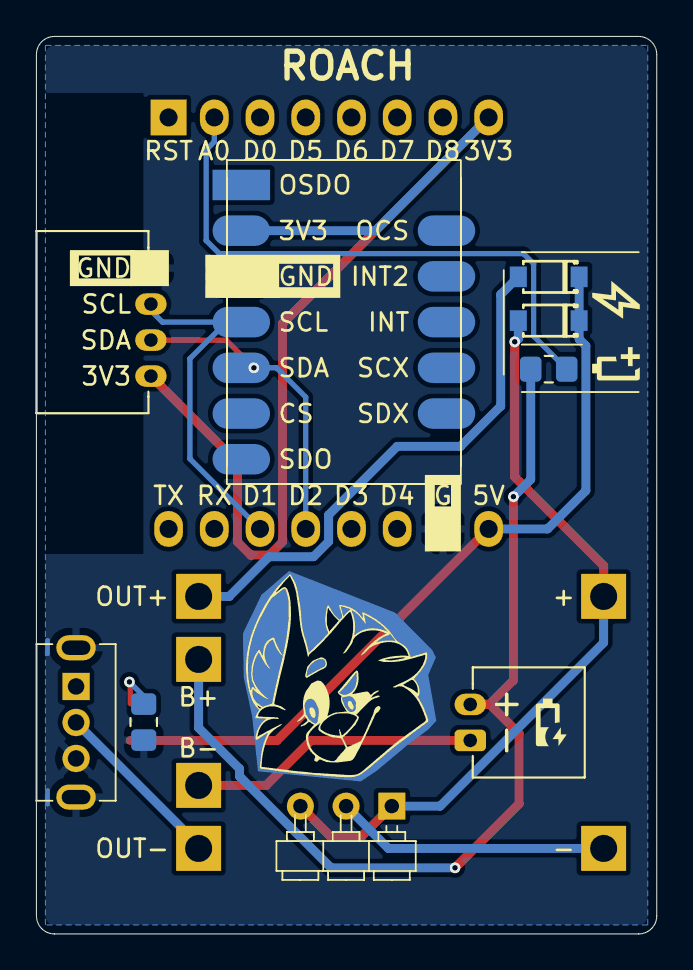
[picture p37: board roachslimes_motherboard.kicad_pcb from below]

Board: 2 copper layers, 34.5 x 49.9 mm, 12 parts (9 on the bottom side), 13 nets.

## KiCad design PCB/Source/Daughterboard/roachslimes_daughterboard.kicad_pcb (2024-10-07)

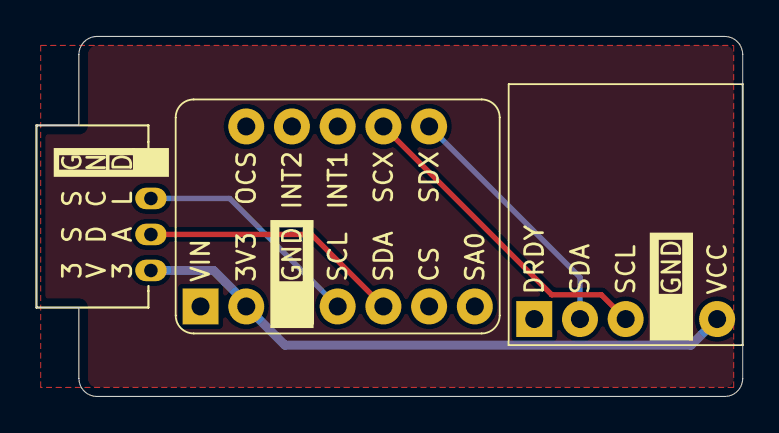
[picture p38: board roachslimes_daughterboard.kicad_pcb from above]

Board: 2 copper layers, 39.2 x 20.0 mm, 3 parts (0 on the bottom side), 6 nets.

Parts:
J1: JST PH 4p; JST_PH_1x4_labelled
U1: BMI160; BMI160_Board_both_sides_1
U2: GY-271; GY-271_both_sides_1

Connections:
+3V3: J1.4, U1.2 (3V3), U2.5 (VCC)
/SCL: J1.2, U1.4 (SCL)
/SCX: U1.11 (SCX), U2.3 (SCL)
/SDA: J1.3, U1.5 (SDA)
/SDX: U1.12 (SDX), U2.2 (SDA)
GND: J1.1, U1.3 (GND), U2.4 (GND)

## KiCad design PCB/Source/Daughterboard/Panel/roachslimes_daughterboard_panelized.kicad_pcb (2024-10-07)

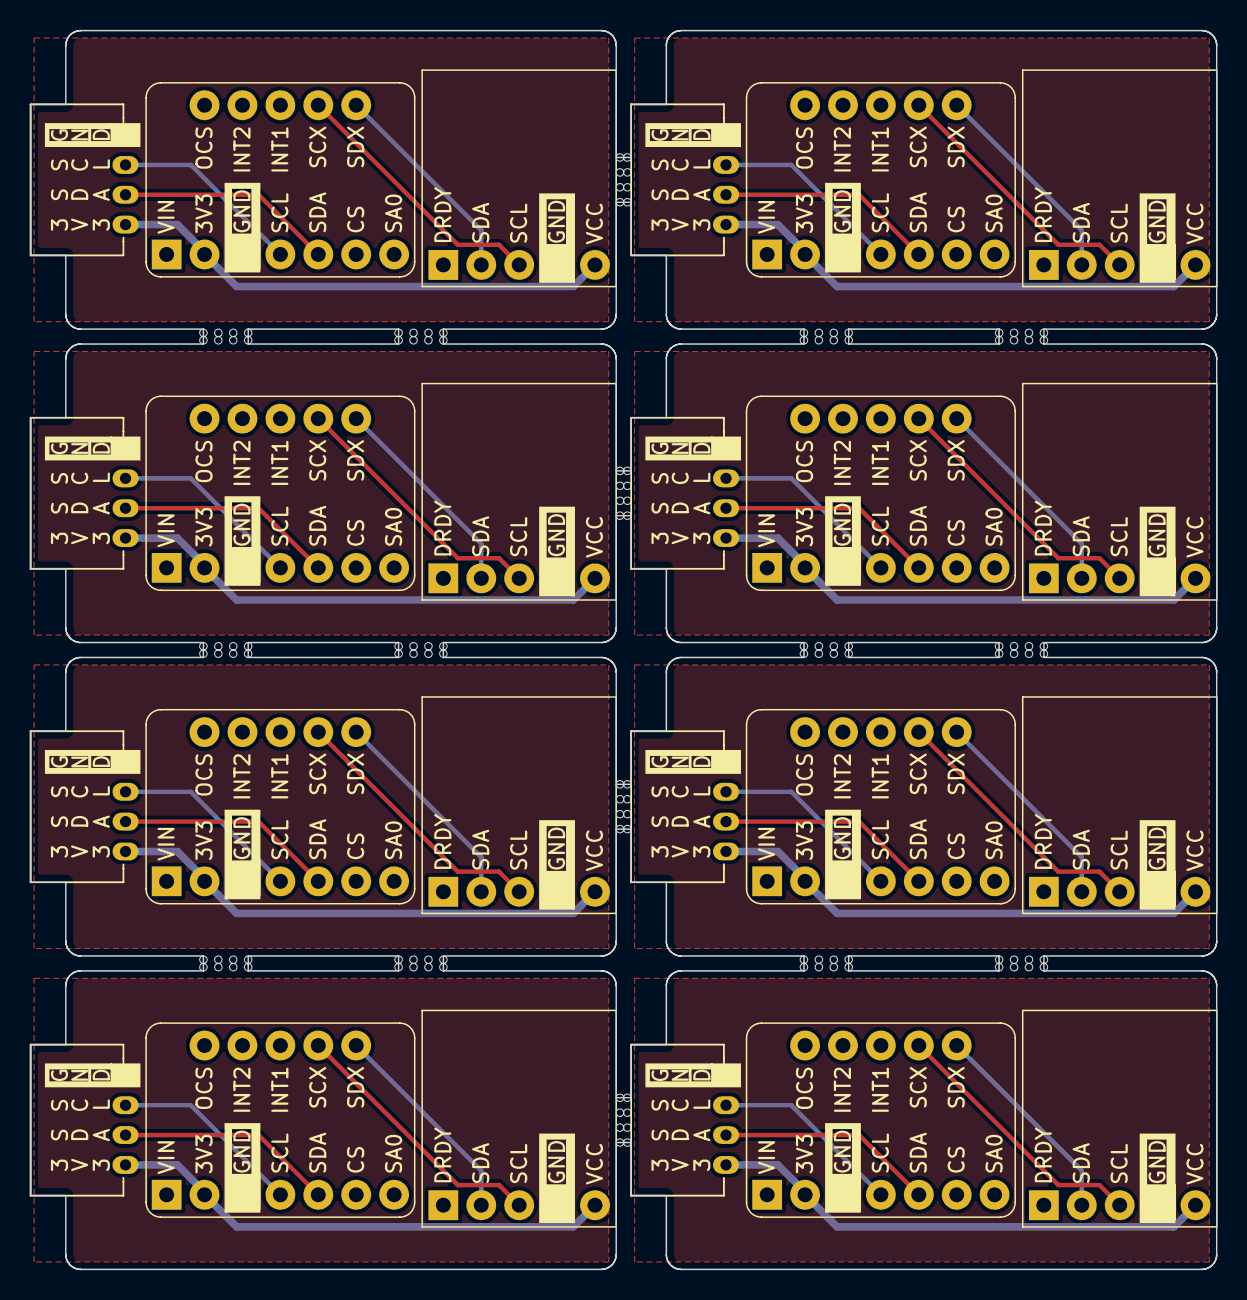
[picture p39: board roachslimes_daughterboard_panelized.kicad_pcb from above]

Board: 2 copper layers, 79.5 x 83.0 mm, 152 parts (0 on the bottom side), 48 nets.

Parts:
J1, J1#2, J1#3, J1#4, J1#5, J1#6, J1#7, J1#8: JST PH 4p; JST_PH_1x4_labelled
KiKit_MB_1_1, KiKit_MB_1_2, KiKit_MB_1_3, KiKit_MB_1_4, KiKit_MB_2_1, KiKit_MB_2_2, KiKit_MB_2_3, KiKit_MB_2_4, KiKit_MB_3_1, KiKit_MB_3_2, KiKit_MB_3_3, KiKit_MB_3_4, KiKit_MB_4_1, KiKit_MB_4_2, KiKit_MB_4_3, KiKit_MB_4_4, KiKit_MB_5_1, KiKit_MB_5_2, KiKit_MB_5_3, KiKit_MB_5_4, KiKit_MB_6_1, KiKit_MB_6_2, KiKit_MB_6_3, KiKit_MB_6_4, KiKit_MB_7_1, KiKit_MB_7_2, KiKit_MB_7_3, KiKit_MB_7_4, KiKit_MB_8_1, KiKit_MB_8_2, KiKit_MB_8_3, KiKit_MB_8_4, KiKit_MB_9_1, KiKit_MB_9_2, KiKit_MB_9_3, KiKit_MB_9_4, KiKit_MB_10_1, KiKit_MB_10_2, KiKit_MB_10_3, KiKit_MB_10_4, KiKit_MB_11_1, KiKit_MB_11_2, KiKit_MB_11_3, KiKit_MB_11_4, KiKit_MB_12_1, KiKit_MB_12_2, KiKit_MB_12_3, KiKit_MB_12_4, KiKit_MB_13_1, KiKit_MB_13_2, KiKit_MB_13_3, KiKit_MB_13_4, KiKit_MB_14_1, KiKit_MB_14_2, KiKit_MB_14_3, KiKit_MB_14_4, KiKit_MB_15_1, KiKit_MB_15_2, KiKit_MB_15_3, KiKit_MB_15_4, KiKit_MB_16_1, KiKit_MB_16_2, KiKit_MB_16_3, KiKit_MB_16_4, KiKit_MB_17_1, KiKit_MB_17_2, KiKit_MB_17_3, KiKit_MB_17_4, KiKit_MB_18_1, KiKit_MB_18_2, KiKit_MB_18_3, KiKit_MB_18_4, KiKit_MB_19_1, KiKit_MB_19_2, KiKit_MB_19_3, KiKit_MB_19_4, KiKit_MB_20_1, KiKit_MB_20_2, KiKit_MB_20_3, KiKit_MB_20_4, KiKit_MB_21_1, KiKit_MB_21_2, KiKit_MB_21_3, KiKit_MB_21_4, KiKit_MB_22_1, KiKit_MB_22_2, KiKit_MB_22_3, KiKit_MB_22_4, KiKit_MB_23_1, KiKit_MB_23_2, KiKit_MB_23_3, KiKit_MB_23_4, KiKit_MB_24_1, KiKit_MB_24_2, KiKit_MB_24_3, KiKit_MB_24_4, KiKit_MB_25_1, KiKit_MB_25_2, KiKit_MB_25_3, KiKit_MB_25_4, KiKit_MB_26_1, KiKit_MB_26_2, KiKit_MB_26_3, KiKit_MB_26_4, KiKit_MB_27_1, KiKit_MB_27_2, KiKit_MB_27_3, KiKit_MB_27_4, KiKit_MB_28_1, KiKit_MB_28_2, KiKit_MB_28_3, KiKit_MB_28_4, KiKit_MB_29_1, KiKit_MB_29_2, KiKit_MB_29_3, KiKit_MB_29_4, KiKit_MB_30_1, KiKit_MB_30_2, KiKit_MB_30_3, KiKit_MB_30_4, KiKit_MB_31_1, KiKit_MB_31_2, KiKit_MB_31_3, KiKit_MB_31_4, KiKit_MB_32_1, KiKit_MB_32_2, KiKit_MB_32_3, KiKit_MB_32_4: NPTH
U1, U1#2, U1#3, U1#4, U1#5, U1#6, U1#7, U1#8: BMI160; BMI160_Board_both_sides_1
U2, U2#2, U2#3, U2#4, U2#5, U2#6, U2#7, U2#8: GY-271; GY-271_both_sides_1

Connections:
Board_0-+3V3: J1#5.4, U1#7.2 (3V3), U2#7.5 (VCC)
Board_0-/SCL: J1#5.2, U1#7.4 (SCL)
Board_0-/SCX: U1#7.11 (SCX), U2#7.3 (SCL)
Board_0-/SDA: J1#5.3, U1#7.5 (SDA)
Board_0-/SDX: U1#7.12 (SDX), U2#7.2 (SDA)
Board_0-GND: J1#5.1, U1#7.3 (GND), U2#7.4 (GND)
Board_1-+3V3: J1#4.4, U1#3.2 (3V3), U2.5 (VCC)
Board_1-/SCL: J1#4.2, U1#3.4 (SCL)
Board_1-/SCX: U1#3.11 (SCX), U2.3 (SCL)
Board_1-/SDA: J1#4.3, U1#3.5 (SDA)
Board_1-/SDX: U1#3.12 (SDX), U2.2 (SDA)
Board_1-GND: J1#4.1, U1#3.3 (GND), U2.4 (GND)
Board_2-+3V3: J1#7.4, U1#6.2 (3V3), U2#8.5 (VCC)
Board_2-/SCL: J1#7.2, U1#6.4 (SCL)
Board_2-/SCX: U1#6.11 (SCX), U2#8.3 (SCL)
Board_2-/SDA: J1#7.3, U1#6.5 (SDA)
Board_2-/SDX: U1#6.12 (SDX), U2#8.2 (SDA)
Board_2-GND: J1#7.1, U1#6.3 (GND), U2#8.4 (GND)
Board_3-+3V3: J1#3.4, U1.2 (3V3), U2#4.5 (VCC)
Board_3-/SCL: J1#3.2, U1.4 (SCL)
Board_3-/SCX: U1.11 (SCX), U2#4.3 (SCL)
Board_3-/SDA: J1#3.3, U1.5 (SDA)
Board_3-/SDX: U1.12 (SDX), U2#4.2 (SDA)
Board_3-GND: J1#3.1, U1.3 (GND), U2#4.4 (GND)
Board_4-+3V3: J1.4, U1#5.2 (3V3), U2#6.5 (VCC)
Board_4-/SCL: J1.2, U1#5.4 (SCL)
Board_4-/SCX: U1#5.11 (SCX), U2#6.3 (SCL)
Board_4-/SDA: J1.3, U1#5.5 (SDA)
Board_4-/SDX: U1#5.12 (SDX), U2#6.2 (SDA)
Board_4-GND: J1.1, U1#5.3 (GND), U2#6.4 (GND)
Board_5-+3V3: J1#2.4, U1#4.2 (3V3), U2#3.5 (VCC)
Board_5-/SCL: J1#2.2, U1#4.4 (SCL)
Board_5-/SCX: U1#4.11 (SCX), U2#3.3 (SCL)
Board_5-/SDA: J1#2.3, U1#4.5 (SDA)
Board_5-/SDX: U1#4.12 (SDX), U2#3.2 (SDA)
Board_5-GND: J1#2.1, U1#4.3 (GND), U2#3.4 (GND)
Board_6-+3V3: J1#8.4, U1#2.2 (3V3), U2#2.5 (VCC)
Board_6-/SCL: J1#8.2, U1#2.4 (SCL)
Board_6-/SCX: U1#2.11 (SCX), U2#2.3 (SCL)
Board_6-/SDA: J1#8.3, U1#2.5 (SDA)
Board_6-/SDX: U1#2.12 (SDX), U2#2.2 (SDA)
Board_6-GND: J1#8.1, U1#2.3 (GND), U2#2.4 (GND)
Board_7-+3V3: J1#6.4, U1#8.2 (3V3), U2#5.5 (VCC)
Board_7-/SCL: J1#6.2, U1#8.4 (SCL)
Board_7-/SCX: U1#8.11 (SCX), U2#5.3 (SCL)
Board_7-/SDA: J1#6.3, U1#8.5 (SDA)
Board_7-/SDX: U1#8.12 (SDX), U2#5.2 (SDA)
Board_7-GND: J1#6.1, U1#8.3 (GND), U2#5.4 (GND)

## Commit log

2024-10-07 added motherboard project files
    [roachslimes_motherboard.kicad_pcb, roachslimes_motherboard.kicad_sch]
2024-10-07 add motherboard production files
    [roachslimes_motherboard.kicad_pcb, roachslimes_motherboard.kicad_sch]
2024-10-07 added motherboard panel
    [roachslimes_motherboard_panelized.kicad_pcb]
2024-10-07 add daughterboard and flush out readme
    [roachslimes_daughterboard.kicad_pcb, roachslimes_daughterboard.kicad_sch, roachslimes_daughterboard_panelized.kicad_pcb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]
2024-10-07 fix minor spelling issues
    [roachslimes_motherboard.kicad_pcb]
2024-10-07 add BOM and adjust readme
    [BOM.xlsx]
2024-10-07 clarify resistor
2024-10-08 add extra parts disclaimer
    [BOM.xlsx]
2024-10-08 update BOM link
2024-10-08 add stl to readme
2024-10-08 remove stl from readme
2024-10-08 Delete PCB/Source/Motherboard/roachslimes_motherboard.round-tracks-config
    delete round tracks fonfig
2024-10-09 add assembly animation
2024-10-09 upload assembly animation
2024-10-09 re-render assembly gif
2024-10-09 update assembly gif
2024-10-09 fix animation of assembly gif
2024-10-10 fix silkscreen in gif
2024-10-10 update assembly animation
2024-10-11 add 3d models, update board renders
    [roachslimes_motherboard.kicad_pcb]
2024-10-14 added r1 case files
    [BOM.xlsx, roachslime_mobo_body.stl, roachslime_mobo_door.stl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]
2024-10-14 add 3mf file
    [cases.3mf, roachslime_mobo_body.stl, roachslime_mobo_door.stl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]
2024-10-14 update BOM to reflect price of cases
    [BOM.xlsx]
2024-10-14 add dabo plug
    [cases.3mf, roachslimes_dabo_plug.stl]
2024-10-14 add fusion source files
    [roachslime_dabo_body.stl, roachslime_dabo_plug.stl, roachslime_daughterboard_case.f3d]
2024-10-14 update case design
    [roachslime_dabo_body.stl, roachslime_daughterboard_case.f3d, roachslime_mobo_body.stl]
2024-10-15 make loop holes bigger (and add orcaslicer file)
    [cases_orcaslicer.3mf, roachslime_dabo_body.stl, roachslime_daughterboard_case.f3d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]
2024-10-15 update slicer files to reflect case changes
    [cases.3mf, cases_orcaslicer.3mf]
2024-10-16 update case locking mech
    [cases.3mf, cases_orcaslicer.3mf, roachslime_mobo_body.stl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]
2024-10-19 finalize case designs, misc edits to readme
    [BOM.xlsx, cases.3mf, cases_orcaslicer.3mf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]
2024-10-20 add assembly.md
2024-10-20 fix title of printing instructions
2024-10-20 fix grammar error assembly
2024-10-20 fix gallery, add 3d print pictures
2024-10-21 make slicer backgrounds transparent
    [cases_orcaslicer.3mf]
2024-10-24 upload v2 cases, update assembly page, add disclaimer to readme
    [roachslime_mobo_body.stl, roachslime_mobo_body_slits.stl, roachslime_mobo_door.stl]
2024-10-24 fix assembly vid
2024-10-28 update model viewer test
    [cases_orcaslicer.3mf, cases_orcaslicer_voron.3mf, roachslime_mobo_door.stl]
2025-01-06 Update assembly.md
    Test video adaptive width
2025-01-11 Update assembly.md
    test scaling css
2025-05-06 attempt to make page wider
    [BOM.xlsx]
2025-08-22 updated v2 case design, added more gallery pictures, and added some more manufacturing files for different printers.
    [cases_anycubic_s1.3mf, roachslime_mobo_body.stl, roachslime_mobo_body_slits.stl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]
2025-09-02 added rev 2, which is designed around the LSM6DSR.
    [roachslimes_motherboard.kicad_pcb, roachslimes_motherboard.kicad_sch, roachslimes_motherboard_panelized.kicad_pcb]
2025-09-03 update dabo_door stl
    [roachslime_dabo_door.stl]
2025-09-04 update PCB images
2025-09-04 update landing page
2025-09-04 update 3d print production files
    [cases.3mf, cases_anycubic_s1.3mf, cases_elegoo_centauri_carbon.3mf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]
